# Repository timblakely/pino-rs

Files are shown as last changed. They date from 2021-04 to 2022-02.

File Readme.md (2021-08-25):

# Pino controller

Bare-metal BLDC controller for Pino the robot, written in
[Rust](https://www.rust-lang.org)!



-----

_**Disclaimer: I'm quite new at Rust, so please bear with me**_

This repository is currently a continuously changing, seething mess as I flail
around learning Rust. You're welcome to browse around the code, but please don't
expect proper, idiomatic Rust code just yet. For that I'd suggest the following
resources:

- [The Rust Book](https://doc.rust-lang.org/book/) - Seriously, read it "cover to cover" as it were. Coming from >15 years of C++ I debated whether it was worth reading the absolute basics, but I ended up going through it all and don't regret it one bit.
- [Embedded Rust Book](https://docs.rust-embedded.org/book/start/registers.html) - I know, I know, another book. But it's quite a bit shorter and more of a getting-started guide to getting Rust up and running in an embedded context.
- [m4vga-rs](https://github.com/cbiffle/m4vga-rs) - Not only is it a downright amazing implementation - 800x600@60FPS VGA on an STM32F4 (!) - the code is entirely in Rust and spectacularly well commented to boot! Definitely the place where I'm learning the most about Rust.

---

## Why rust?

I originally started the controller in C++, but found myself spending more and more time thinking about the language implementation, template metaprogramming, and wrestling with the inability to `constexpr` a raw address (can't `reinterpret_cast<Foo>` an address in a `constexpr`, but [don't take my word for it](https://www.youtube.com/watch?v=uwzuAGtAEFk&t=1217s)...), and less time on the actual controller itself. That's when I stumbled on Cliff Biffle's post with the contentious title "[Prefer Rust to C/++ for new code](http://cliffle.com/blog/prefer-rust/)". He posits that Rust was ready to replace C++ in most-if-not-all situations, _and that was back in 2019_. That post single-handedly convinced me to try out Rust, and I haven't looked back since.

## Building it

Don't bother trying right now; it doesn't really do anything :stuck_out_tongue_winking_eye:

But if you _really_ want to:

1. ```cargo build```
2. Connect your [NUCLEO-G474RE](https://www.st.com/en/evaluation-tools/nucleo-g474re.html), and follow the [Embedded Rust steps for adding the proper udev rules](https://docs.rust-embedded.org/book/intro/install/linux.html#udev-rules)
3. In VSCode, select `cortex-debug` launch configuraiton
4. Hit `F5`

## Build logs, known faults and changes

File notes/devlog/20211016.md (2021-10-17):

# Un-bricking STM32G4

Well that was scary. For some reason when Iw as flashing the chip it suddenly started saying "Error erasing flash with vFlashErase packet".
- Not sure what tripped it up, but no amount of disconnect/reconnecting or power cycling could revive the chip
- Thought I had fried it D:

Luckily I stumbled on [this thread](https://www.openstm32.org/forumthread2221) that had a solution:
- `openocd -f interface/stlink.cfg -f ~/git/rembed/tools/stm32g4x_custom.cfg` in one terminal to start OpenOCD session
- Then in another, run the following commands:

```
$ telnet localhost 4444
> reset halt
> flash probe 0
> flash protect 0 0 127 off
> exit
```

TL;DR: Somehow the flash protection got enabled, and the version of OpenOCD I'm using doesn't properly disable it before attempting to flash.

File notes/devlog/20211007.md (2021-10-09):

# We now return you to our regularly scheduled bot

Okay, I've been quite lax in self-documentation recently. Time to fix that!

I'm working on organizing my Rust workspace now. I've mainly been talking to the BLDC via Python->PySerial->FDCANUSB->BLDC, but something in that loop is causing some pretty serious latency, to the point where I can only poll at like 45Hz. That's waaaay too slow for any kind of monitoring. I suspect it's somewhere in Python+PySerial, so I'd like to cut that out of the loop. Then it hit me: if I like Rust so much, why not do the serial communication from Rust?
- First stab was the [serial](https://crates.io/crates/serial) crate. Buuuut turns out that hasn't been updated in 4+ years and is pretty out of date with modern Rust
- Next try is with [serialport](https://crates.io/crates/serialport). Better so far
- Also needed an `argparse` for Rust. [clap](https://crates.io/crates/clap) to the rescue!
  - The base configuration is a bit verbose/unwieldy, but it'll do for now.
  - [clap_derive](https://crates.io/crates/clap_derive) might help with that
-

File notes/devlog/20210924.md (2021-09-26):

# Closer to FoC

First up is moving away from the interrupt-driven angle calculation and instead towards a polling model. Done

Was trying to figure out why Ben was [casting the raw 0-1 encoder reading to an int prior to conversion to radians](https://github.com/bgkatz/motorcontrol/blob/2fa6cabbebcb19efb9d6b2dd0f59edc3537ad64f/Core/Src/position_sensor.c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)
  - I _think_ it has to do with the fact that you can set the mechanical zero (`M_ZERO` in his code) to any value within the range which can result in negative values, so it normalizes the corrected value from 0-1
- Interesting that he has an electric zero and mechanical zero separated

Now I guess all that's left is FOC...?
- I guess I do have to get the CORDIC calculations done, so I guess that comes first

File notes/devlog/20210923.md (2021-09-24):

# Encoder angle

Time to get electrical angle and velocity
- MA702 is already being auto-polled at 1kHz
  - Datasheet suggests new data is added to SPI every $1\mu s$
  - Doesn't really produce data changing that fast though since there's a ~390Hz filter cutoff frequency
- The stator has 12 poles, which gives us an electrical resolution of
  $\frac{2^{12}}{12}=\frac{4096}{12}=341.333$ ticks, or just over 8.41 bits

So how to deal with time...
- I've got three distinct time intervals:

1. The control loop of 40kHz (25us)
1. The MA702 polling loop via SPI of 1kHz (1ms)
1. The digital filter on the MA702 with a cutoff frequency of 380Hz (2.56ms)

- As far as I can tell I _think_ the last is accounted for with time delays in the control loop
- I can get the raw angle - both electrical and physical (EP) - easy enough; that's just reading the sensor
- The trick is how to calculate the _angular velocity_
  - It's required in two places: the finer grained direct EP angle via estimation, and the FOC calculations
- I think the underlying velocity calculation can probably be done within the `Encoder` struct, assuming we call an `.update(dt)` function once every control loop.

First up, get the MA702 to record velocity
- That'll require knowing the difference in time between updates. I guess only way to do that is by triggering on DMA
  - I guess I could use a timer, but would probably have to use a 32 bit timer; I'll cross that bridge when I have to
- Okay, have the DMA1 interrupt triggering
- Now I've got a bit of a problematic situation: both the DMA1 interrupt handler _and_ the 40kHz control loop need access to the result of the MA702
  - DMA1 needs it to read the encoder value and calculate the angular velocity and acceleration at 1khz
  - The control loop needs it to update the Encoder's finer grained representation via $\dot{\theta}=\ddot{\theta}dt$ and $\theta=\dot{\theta}dt$
  - I _think_ I may have conquered this problem once before via `BufferedState`. The high frequency control loop is read-only, so the lower priority DMA1_CH2

Okay, got that going. Seeing some odd readings on the raw_angle though... it's supposedly 12 bits but it's going to ~4658
- Thought it might have been garbage being written, but turns out I had `>> 3` instead of `>> 4`

Oof, running into a gotcha with buffered_state: I can't count on previous values being correct since the state is being double-buffered; the previous value would be in the other state
- Looks like I'm going to have to add one more layer of indirection to avoid blocking the control loop
- Wait, actually this works out pretty well: I can use the other buffer as the previous value since it's read-only in the `StateReader`
- Yup, that works. Now able to get the angle at 1kHz and soon interpolate it even more
- Though now that I look into it, it seems like in spite of the filter being at 380Hz, it can produce data faster than that, at up to 1MHz... so this might have been superfluous?

Working on DMA auto-transfer from MA702, but something's a bit weird...

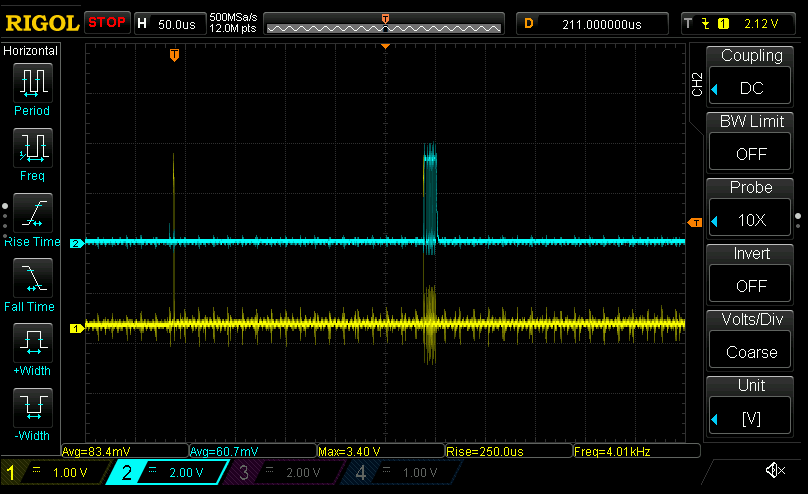
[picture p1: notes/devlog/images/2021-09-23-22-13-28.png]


- That first yellow pulse is when I enable the interrupt. That second yellow pulse is when the DMA transaction complete signal hits. That transfer _should_ be driven by the SPI completion
- But instead it appears to be on when the SPI transaction _starts_
  - Digging into the DMA settings now; I likely swapped `DMA[CH1]` (used to trigger the SPI transaction) and `DMA[CH2]` which is triggered by the SPI frame completion
- Aha! That's more like it

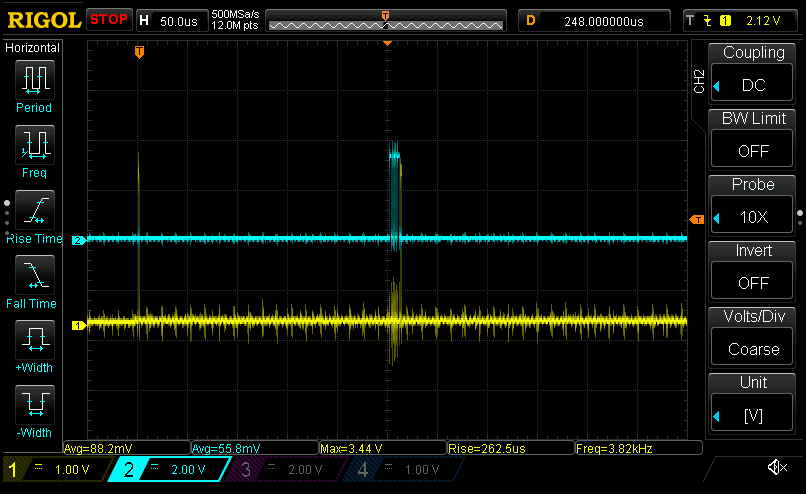
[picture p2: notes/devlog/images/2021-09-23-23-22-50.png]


  - Zooming in:

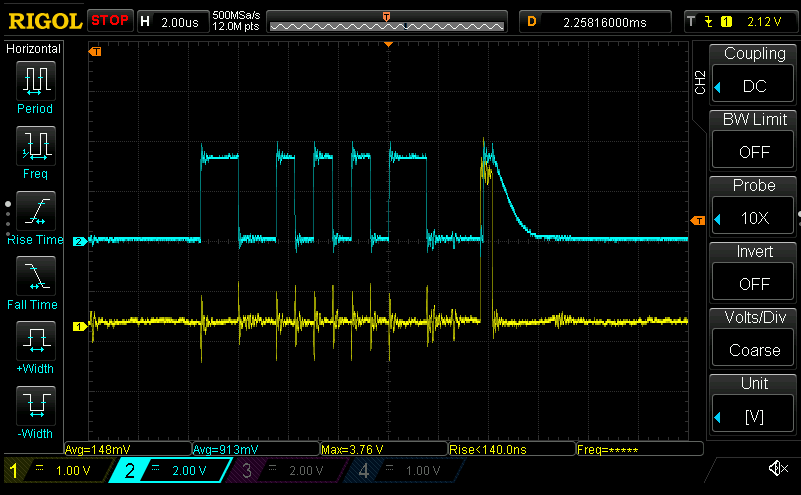
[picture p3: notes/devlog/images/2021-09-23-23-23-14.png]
    

  - Copy-and-paste strikes again... I had set up `DMA[CH1]` trigger correctly, but during copy/paste setting up `CH2` I didn't end up changing the DMA trigger from `TIM3_UP` to `SPI1_RX`
  - Oops? Oh well, at least it was pretty quick to fix
- Ooh, wait... since this is done via DMA I wonder if I can poll the encoder _even faster_ than my control loop
  - The DMA controller can execute a write every 4 AHB cycles, which mens at 170MHz it can run at 42.5MHz
    - Pretty overkill, since the SPI is only at like 5MHz or something like that :sweat_smile:
  - Looks like as long as I don't use the interrupt-driven version I can poll it at 100kHz and have about 4us of play assuming I run the SPI at $\frac{170MHz}{64}=2.656MHz$

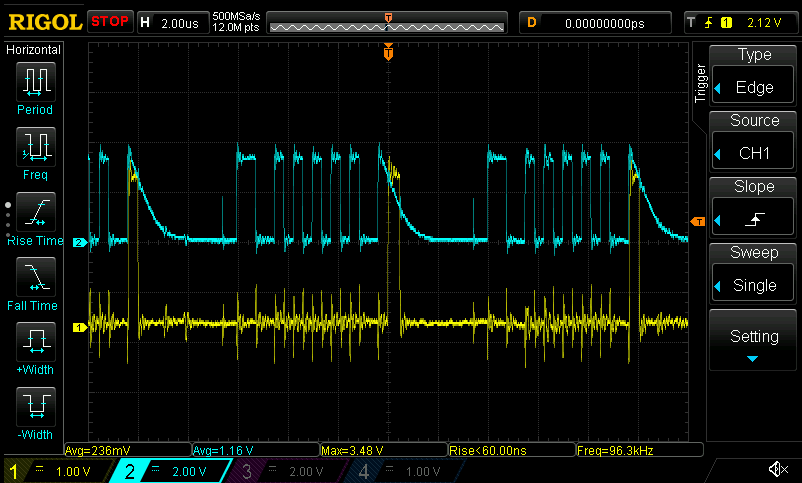
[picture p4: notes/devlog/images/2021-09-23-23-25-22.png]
    

- 100kHz is complete overkill of course since I'm only actually reading the value once every 40kHz in the control loop
  - But there's one big advantage to doing it via DMA: there's effectively zero overhead during the control loop waiting for the SPI to read out the angle
  - Even assuming you're doing it asynchronously, unless you pack various other instructions _perfectly_ between the start-SPI-read and read-out-once-SPI-transaction-is-done you're going to be wasting upwards of 1-5us
  - That doesn't sound like much, but when your control loop is operating at 40kHz that means you've got 25us _total_ to play with

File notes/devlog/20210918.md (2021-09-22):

# Controlling the currents

We have current control! :zap:
- Took me a while to realize what the issue was that was causing runaway current after about 20 timesteps
- But realized by PWMing phase A to get a current on phase A, the current measured is actually negative
Makes it hard to reach a positive current... :sweat_smile:
- Now to implement rudimentary FOC and we should have some motion!

So it's _really_ noisy due to ~~my boneheaded mistake~~ issues with the ground plane, but it looks like I have current control for sure
- Here's me commanding -1.5A on Phase A, as measured from the output of the DRV8323's CSA

  

- And here's the response asking for -3.5A

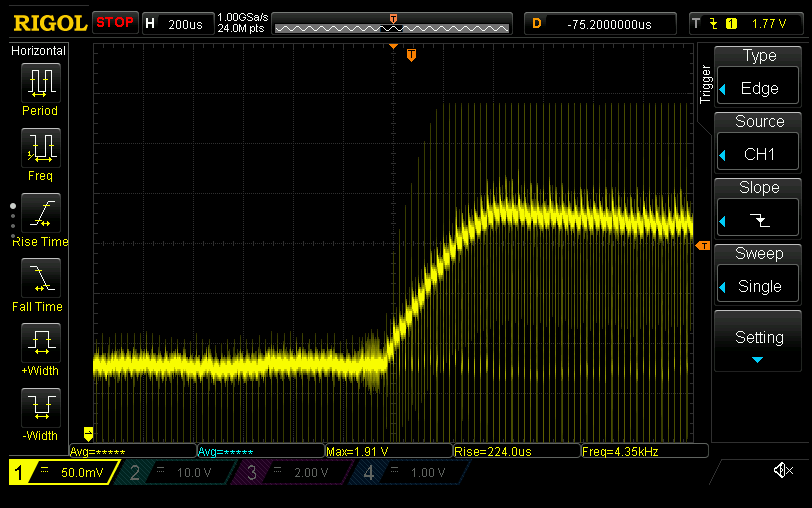
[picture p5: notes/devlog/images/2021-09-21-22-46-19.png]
  

  - Ugh, that noise is going to drive me absolutely _nuts_ until the global semiconductor shortage is over and I can actually fab new boards
    - Which will be approximately.... never? :sob:

- If you squint really hard though, there's actually a control loop there that looks just about what I'd expect given my modeling
- On top of that I don't really have a good place to ground my probe, so I'm literally steady-pinky-holding the ground clip to the negative side of my bulk caps, which I'm sure is great for noise suppression...

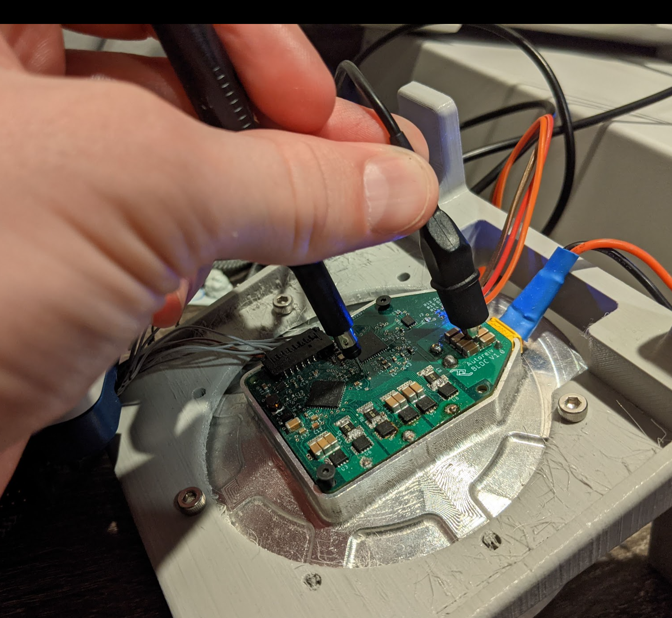
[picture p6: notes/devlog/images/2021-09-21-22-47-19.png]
 

  - Why yes, now that you mention it I _am_ going to be 1) adding a ground pad to clip onto on rev 1.1 and 2) getting a proper PCB probing setup when I finally move to a workshop bigger than a shoebox
    - Please don't judge me too harshly on my SMD soldering skills... this was my first board design, SMD soldering attempt, use of 0402 parts, flux, and a heat gun ever (honestly I'm gobsmacked it turned on at all)
  - You better believe I'm going to be upgrading the I-can't-believe-it-hasn't-broken-yet debug header/wiring for rev 1.1 :zany_face:

So here's something interesting... I was wondering why I was seeing some nice, smooth current control curves like this commanding -6.5A on phase A

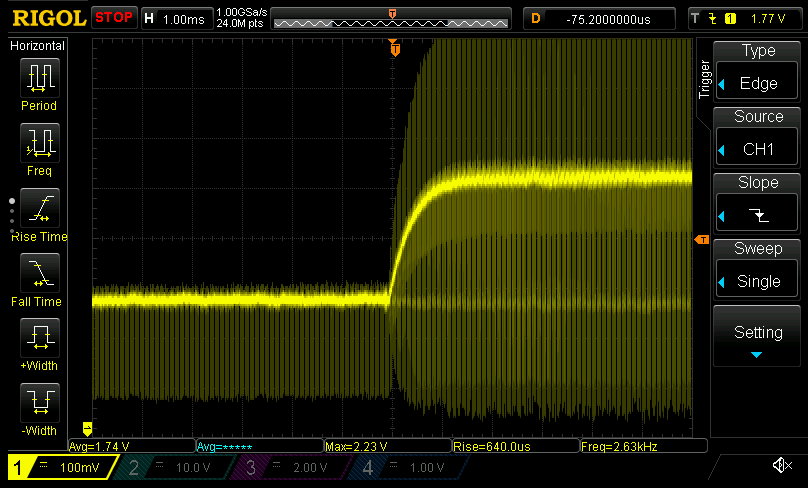
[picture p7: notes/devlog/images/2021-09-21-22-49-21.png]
  

- That definitely looks like a controlled rise; all good!
- But the rise time to peak was 1ms. That's borderline "wait, [wat](https://www.destroyallsoftware.com/talks/wat), that's pretty slow, and way too slow during any kind of gait to be changing torque targets"
- This is in contrast to Ben's controller could hit the appropriate currents in <= 500us

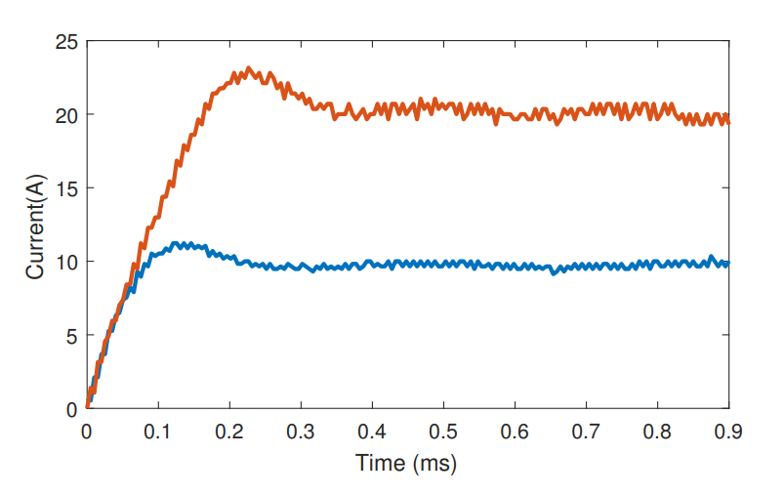
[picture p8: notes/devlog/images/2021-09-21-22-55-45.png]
  

# ***SIGH***

I had Forgotten yet ***another*** hardcoded value I added to the codebase
- Back when I was doing inductance and resistance measurements/calibration, I couldn't allow the PWM to get higher than a certain value or risk driving 100A through my stator
  - Just trying to prevent this (not mine, thankfully!)

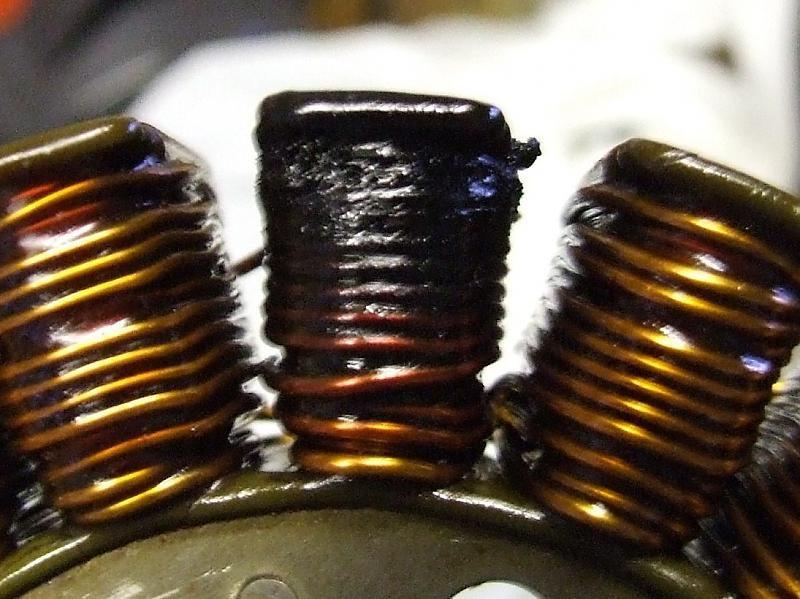
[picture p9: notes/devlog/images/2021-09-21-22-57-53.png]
    
- With that hardcoded value my current loop was clamped to driving a maximum of +/- 1.5V in case the current loop didn't work
- Remove that and lo and behold: I can hit 0->10A in just over a hundred us, just like Ben's case above

  

  - Note that his simulations above are running faster than the 40kHz my measurements are made at. From what I can tell from the graph above the motor sim is running at a loop speed of 100kHz

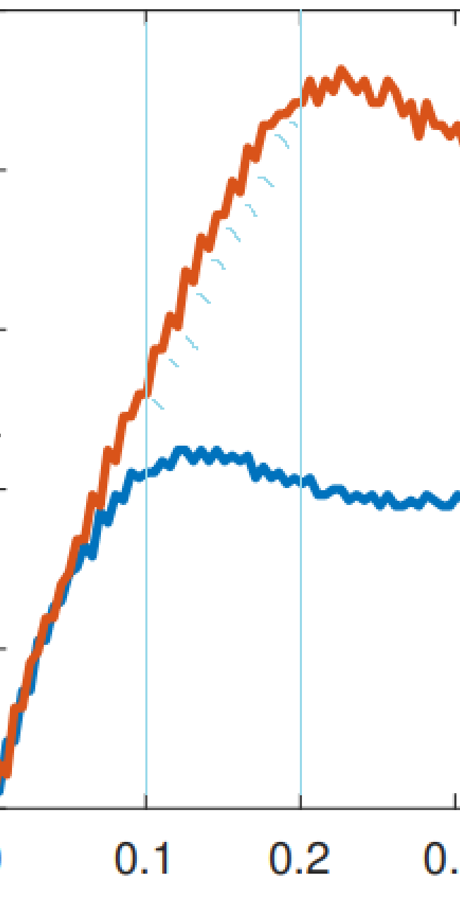
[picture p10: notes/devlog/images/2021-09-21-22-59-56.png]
    
    - (That's 10 ticks per 100us)
  - He had a (much) older control loop running at around 10kHz that reached a step function of 1A in about 1.55ms, so this seems acceptable

    
- Again, my k/ki are probably way needlessly accurate, but hey, can't complain with a bit more performance

Last amusing anecdote for the evening
- Was wondering why I couldn't get above 16A on my current step
- ... turns out I had yet _another_ (***are we seeing a pattern yet Timmay?!***) hardcoded limit that said if the board detected a current above 20A to shut down
- So considering my amplifiers are a bit noisy and there's probably a bit of overshoot for the control loop, I added a low-pass filter on the phase current (`alpha = 0.01`)
- ***BBZZZZTTTT*** aaaand my psu started going nuts
  - ... oh, I had the current limit set to 1A and OCP set to 2.5A. No wonder it couldn't supply 16A :zany_face:

    

Alright; TL;DR for today:
- I have current control, and didn't blow up my stator getting to this point :sweat_smile:
- In addition to that: my inductance calibration + resistance calibration + control loop gain calculations were accurate enough to effectively auto-tune a control loop for 2kHz bandwidth! :tada:
- Just a few more steps away from FOC commutation

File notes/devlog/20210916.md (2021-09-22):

# Bad inductor, bad

Hm. Well, looks like I'll have to dig back into the inductance calibration code again :/
- On one hand, hooray my LCR meter came today!
  - AFAICT it's a not-entirely-terrible cheapo LCR meter that trades a crappy updates-once-per-second display for somewhat accurate internals
  - It's not a great one by any means, but I've tested it against a few Cs and Ls that have a known-ish value and it's surprisingly accurate
  - [DE-5000](https://www.amazon.com/gp/product/B00S298KJO/) - Amusingly even the instructions were in Chinese
  - It's a step up from the typical craptastic LCR meters since it does variable frequency measurements at  100, 120, 1k, 10k, and 100kHz
  - Still definitely better than the ~$35-range ones
  - One positive: it can measure DC resistance down to 1/100th of an ohm, which is nice (two (three?) orders of magnitude better than my decent multimeter)
- On the other hand it's measuring an inductance of ~100uH whereas my calibration routine above said it was around 25uH :thinking:
- Being close is fine, but being off by a factor of 4x is Not A Good Thing™️
  - Dang... was hoping to have solved the inductance issue

The inductance measurement from the LCR of 100uH was phase-phase, not overall
- I suspect it's due to a bug or two in my inductance measurement code. At this point - considering I've already found one bug - I trust the LCR more than my calibration code
- Given the square wave I was driving through the stator was going through A and out B and C, that means I've got a few in series
  - Which means each individual phase is < 25uH I was measuring...
- Yeah, something isn't quite right :/

I was initially thinking I wasn't doing the ADC conversion correctly
- But the v_bus rail I'm reading through ADC4 shows... wait for it... gotta remember how to do it :sweat_smile: ....
- 23.91V. That does seem a bit low, given the PSU rail output is almost exactly 24V
- But I don't think a 0.375% error can make a 4x difference in inductance measurement...?
- Just really wish I hadn't screwed up the ground plane... really going to limit my current loop bandwidth with how noisy phase B is :/

  

***sigh*** And yet again, turns out very likely [PEBKAC](https://en.wikipedia.org/wiki/User_error)
- `let v_ref = v_bus * 0.03; #PWM hardcoded to 0.03` ***Not if it's a parameter you're sending now that you've changed the loop to be configurable via FDCAN!!!*** :woozy_face:
- TL;DR: Timmay is a dummy... turns out when I correct that hardcoded value above to the correct PWM'd value I get anywhere from 100-112, which is exactly what the LCR meter suggests it should be
- 
- Silver linings? 1) My inductance calibration now works (ish) 2) I have zero buyers remorse from the LCR meter :zany_face:

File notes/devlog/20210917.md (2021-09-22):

# Current control loop design

Okay! I think, after ~~a few days~~ ~~weeks~~ _entirely) too long, I think I've gotten all the
parameters set up to do my PI controller loop!
- Can now calculate the $k$ and $k_i$ values I need, and the loop gain to translate from current to voltage
- Here's a bode plot (please do ignore Octave's terrible UI) of the control parameters I've measured

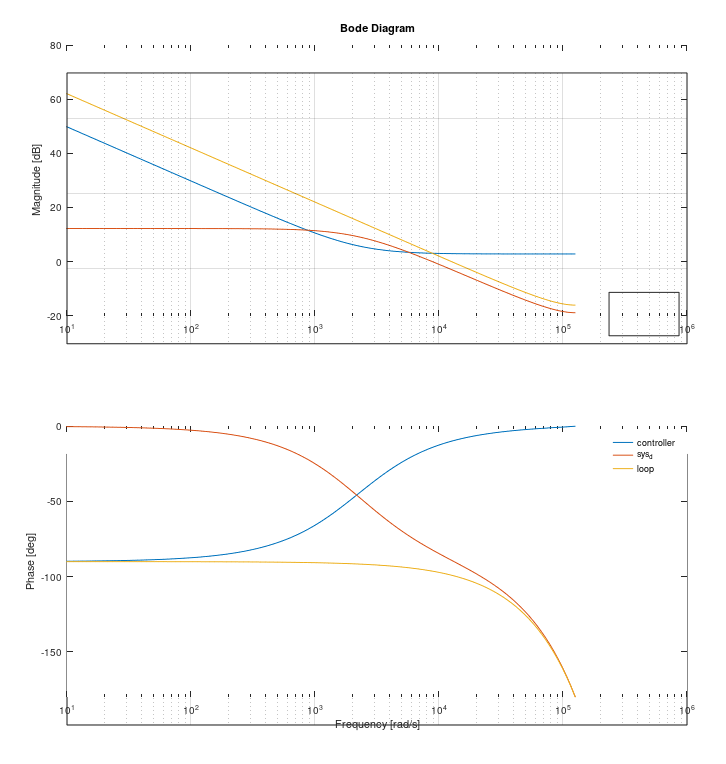
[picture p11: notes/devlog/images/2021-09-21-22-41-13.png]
  
- That's with a loop bandwidth of 2kHz (and a PWM/sensing loop of 40kHz)
- Given my awful ground plane goof, I'll probably lower that to something like 1.5-1kHz
  - Makes up for the fact that there's a tiny vuvuzela blasting its little heart out at 700kHz on Phase B :trumpet: :woozy_face:
- Decent phase and gain margins too

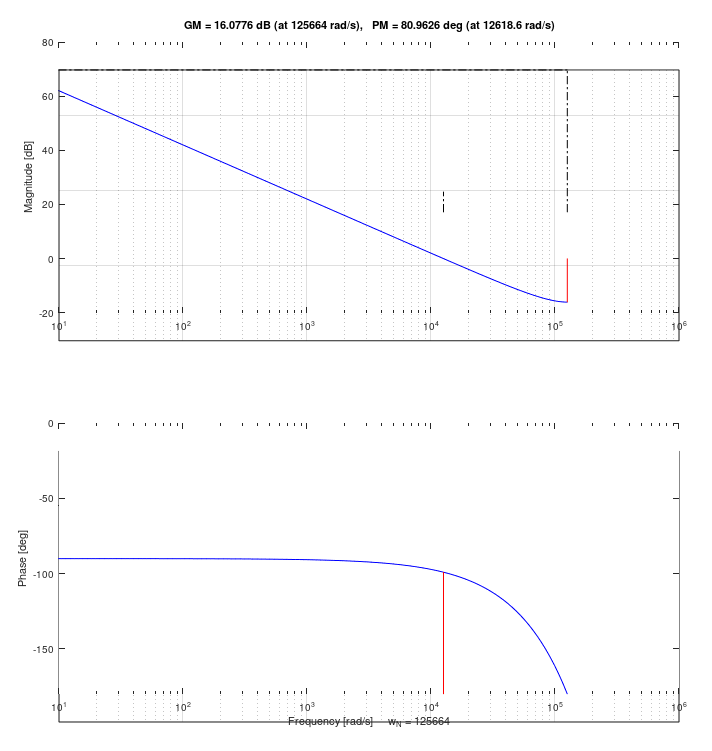
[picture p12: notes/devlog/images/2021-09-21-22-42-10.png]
  

I realize I'm just going through the motions here with regards to control theory
- Any quad motion/feedback that's likely to happen in a physical system is almost certainly going to be an order of magnitude lower than the loop bandwidths I'm targeting
  - It's mainly about some blend of "trying to understand what's going on" and "trying not to asplode anything since I barely know what I'm doing", in just about equal parts :sweat_smile:
- Step response going from 0-1A on the theoretical controller

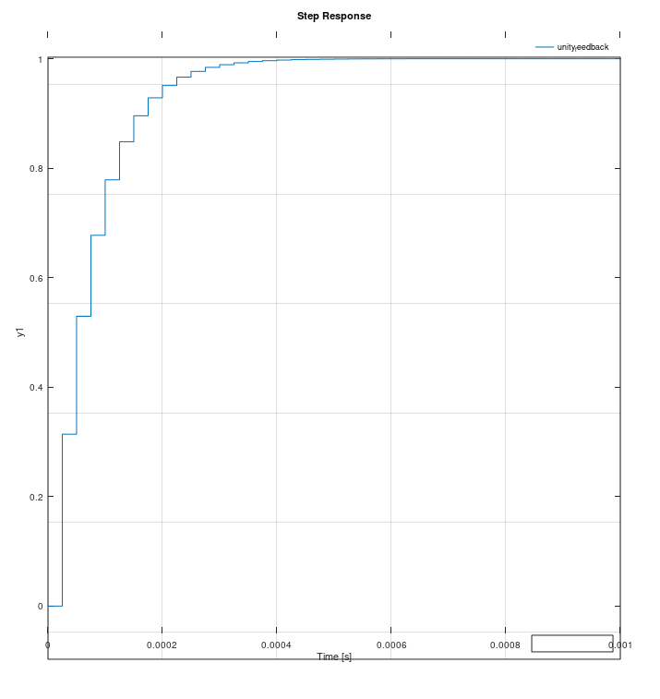
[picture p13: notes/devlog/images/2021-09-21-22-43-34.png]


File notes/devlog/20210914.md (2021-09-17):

# Current loops

Working on figuring out the current gains on the following assumptions:

- Inductance: 24-26 $\mu H$
- Resistance: 240mOhm

Going to work through Ben's model, Appendix C from this thesis.
- Electronic dynamics of the system (RL) are several orders of magnitude faster than mechanical, so reasonable to ignore those dynamics

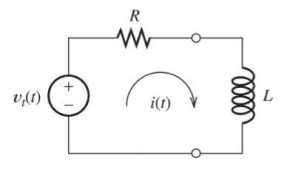
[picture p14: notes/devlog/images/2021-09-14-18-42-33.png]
  
- Continuous time _system_ transfer function is $\frac{\bar{Y}(s)}{\bar{u}(s)}=\frac{I(s)}{V(s)}$
  - $V(t)=\underbrace{L\frac{dI}{dt}}_{inductor} + \underbrace{RI(t)}_{resistor}$
  - Laplacian gives us $V(s)=LsI(s)+RI(s)$
  - Building transfer function:

$$
\frac{\bar{Y}(s)}{\bar{u}(s)}=\frac{I(s)}{V(s)}=

\frac{I(s)}{LsI(s)+RI(s)}=\frac{I(s)}{(Ls+R)I(s)}=\frac{1}{Ls+R}
$$

- - Neat, derived that on my own and it matches Ben's results :)

So system transfer function is $\frac{1}{Ls+R}$
- Looks like there's a pole at $s=-\frac{R}{L}$
- Note that in the standard format the $\frac{1}{as+b}$ means it has a DC gain of $\frac{1}{b}$, or in this case $\frac{1}{R}$ ([good resource](https://www.allaboutcircuits.com/technical-articles/understanding-transfer-functions-for-low-pass-filters/))
  - DC gain is the $abs$ gain in Ben's bode plots

    
- Keep in mind that this is the _system/plant_ transfer function, not the true _loop_ transfer function that includes the controller $K$

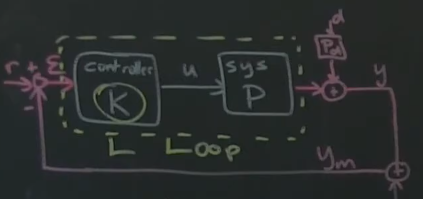
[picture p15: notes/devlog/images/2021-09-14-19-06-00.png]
  
  - That means the whole loop transfer function of the whole system is $L=PK$

Note that $\frac{1}{Ls+R}$ is in _continuous_ time, and that's not where we operate; we're in discrete
- Conversion from continuous to discrete via [z transform](https://www.youtube.com/watch?v=14cMhrp5wlk&list=PLUMWjy5jgHK0MLv6Ksf-NHi7Ur8NRNU4Z) ([neat visual representation](https://www.youtube.com/watch?v=acQecd6dmxw))
  - $\mathcal{Z\left(f[k]\right)=\sum\limits_{k=0}^\infty}f[k]z^{-k}$

  
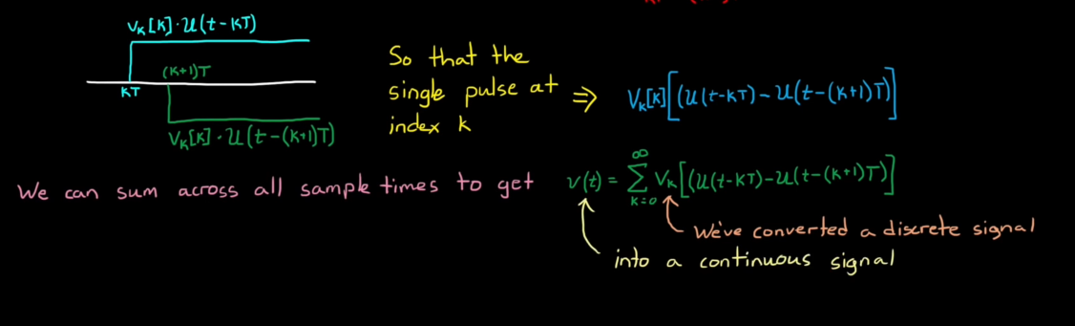
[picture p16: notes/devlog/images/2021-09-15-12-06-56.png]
  
  
  
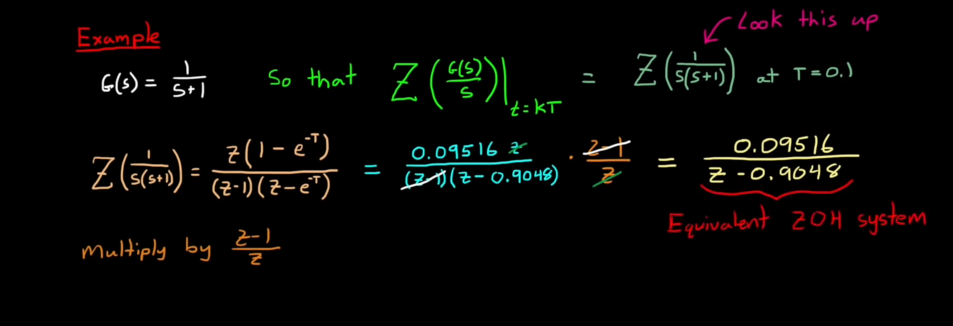
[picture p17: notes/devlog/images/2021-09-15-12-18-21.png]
  

Ben used a zero-order-hold conversion to discrete time

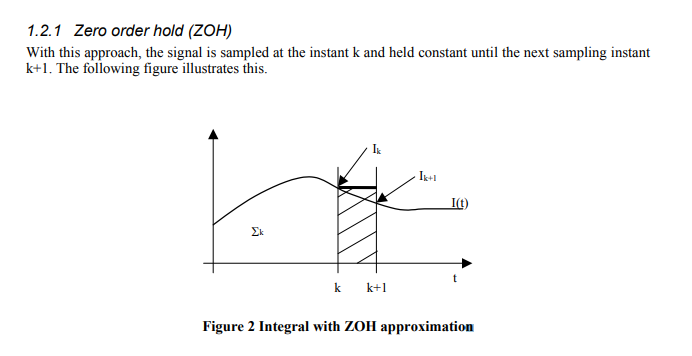
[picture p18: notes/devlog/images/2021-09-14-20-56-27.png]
  

  ([source](https://www.analog.com/media/en/technical-documentation/application-notes/PI_ctrl.pdf))

  $U(z)=K_p\cdot\left(1+\omega_{pi}\cdot\frac{}{}\right)$

  $\liminf\frac{1}{x}$

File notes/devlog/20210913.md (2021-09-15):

# Easy goal: measure resistance

Hopefully a quick goal this evening: measure the phase resistance for phases A/B/C

Less quick than I'd have hoped since I was getting some slightly odd values of 330+ mOhm, but got it
sorted
- _On tonight's riveting episode of "Graphs Nobody Should Care About" we bring you... phase resistance!_

  

  - Looks like I'm measuring around ~240 mOhm asymptotically
  - The end dip is my ControlLoop hardcoded limit of 0.08 duty cycle kicking in
  - Note that this is sensing for only 0.25s. I can probably get a slightly more accurate reading if I sensed for longer
- The motor manufacturer claims they can sustain 8A continuous, but a) that almost certainly has to be over-estimated by a decent margin and b) given the global silicon + supply chain armageddon I reeeeeeeeeeeeeeeally don't want to destroy one of my <= 3 actuators I have for the next 1-5 years D:
- You know what, here goes nothing. Going to try to measure for - ***gasp*** - 0.5s. Will report back either with results or very-angry-at-himself-for-knowing-his-luck-gonna-wreck-his-stator-Timmay...
  - Reporting in: neither my stator nor house are on fire :fire:
  - Again, very similar response:

    
  - Asymptotically it's right around 240 mOhm yet again
  - 240 mOhm is right in line with what I can measure with my multimeter across a single phase: 0.1<R<0.2 Ohm

Okay Tim, STAHP characterizing the motor already!
- We have inductance and resistance of the motor now
- We can pass it on to Future Tim to design the current control loop gains

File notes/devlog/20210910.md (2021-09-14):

# The Case of the ~~Missing~~ Noise

This ADC noise is really starting to bug me
- First up I moved calibration to be done via a `ControlLoop`, currently triggered via RPC
  - Probably can set this during startup, but for debugging purposes this is fine
- Before/after calibration:

  
  - Pretty cool that I can do this via Python now
  - Looks pretty good, but then there's still some wonky noise on ADC2:

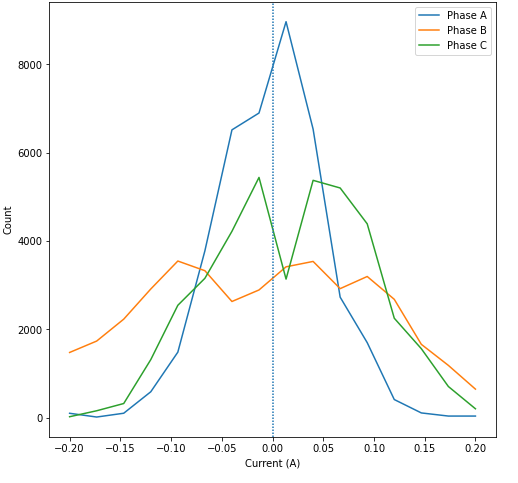
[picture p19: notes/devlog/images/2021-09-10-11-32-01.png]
    
- Okay, I just convinced myself it's switching noise. Here's a trace of Phase B's sense line:

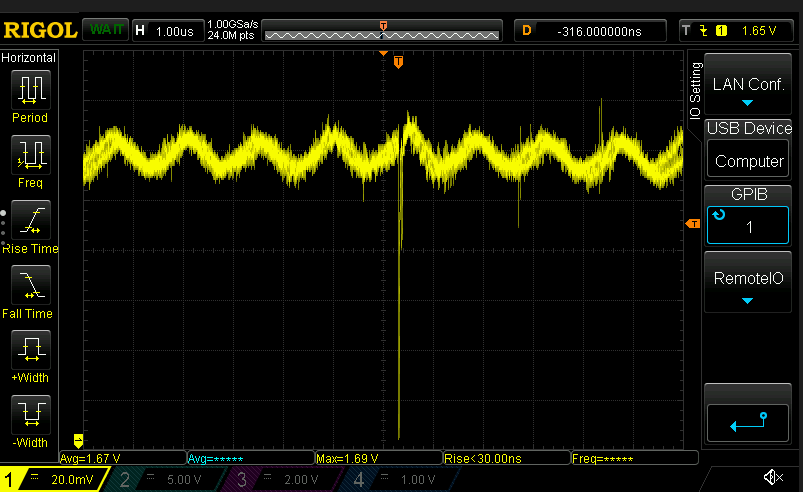
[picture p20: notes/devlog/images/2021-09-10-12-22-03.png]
  

  - And guess what? If you zoom out a bit and do an FFT...

  

  - Ayuuuup. 700kHz. And guess what the switching frequency of the DRV8323R is... :woozy_face:

- Here's a probe between the 24V ground and the logic ground:

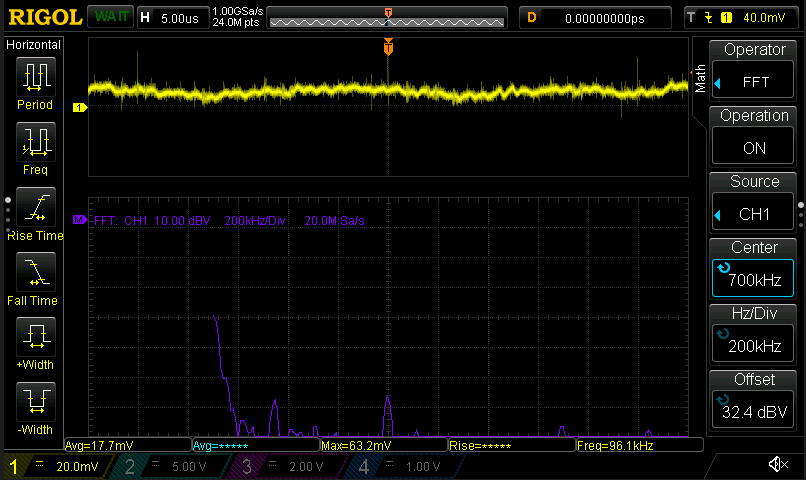
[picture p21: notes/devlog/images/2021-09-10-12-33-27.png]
  

  - No getting rid of it on this board revision :(

Turns out I made a ***major*** screw-up when designing this board revision: I split the ground plane

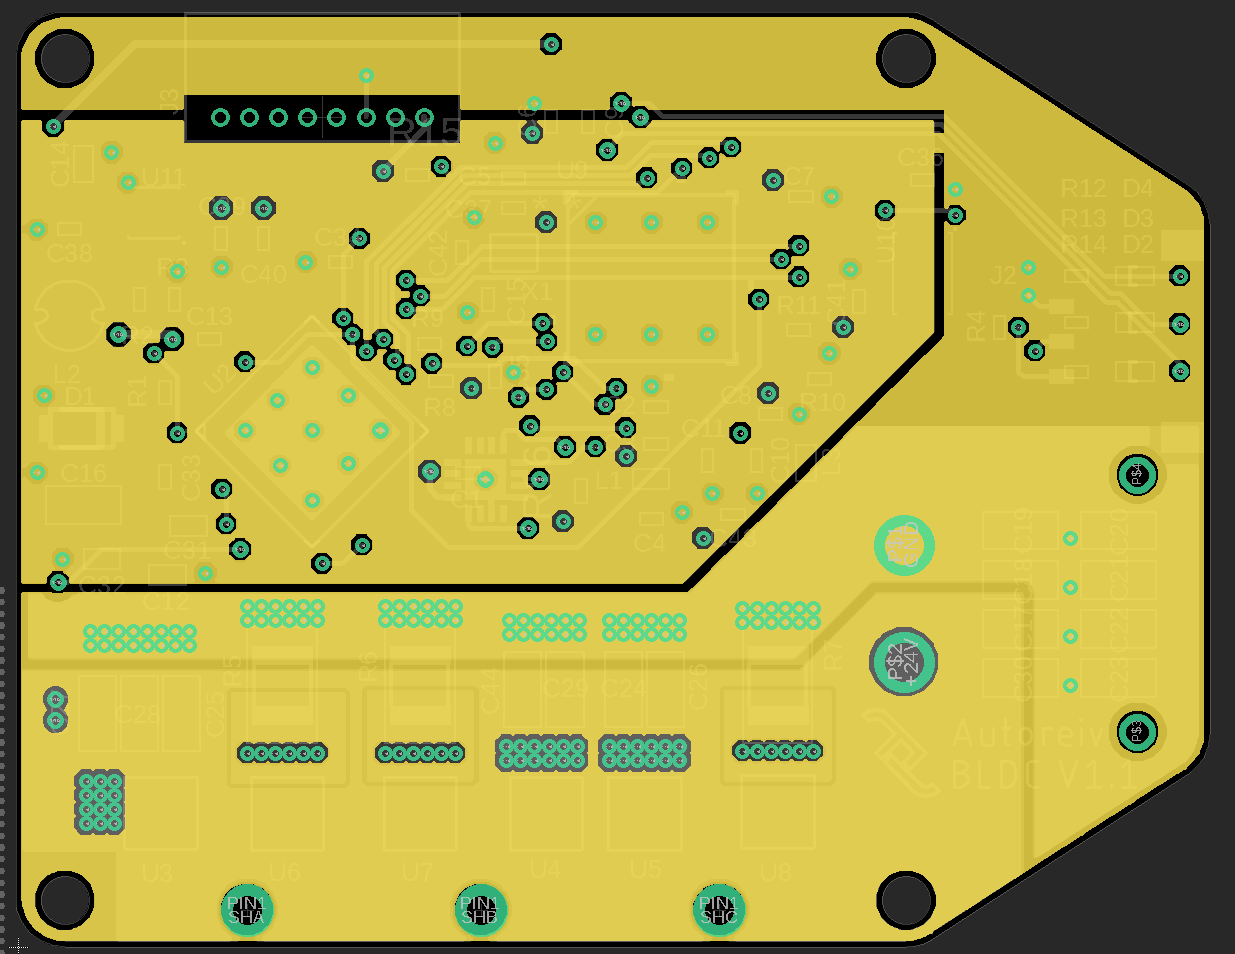
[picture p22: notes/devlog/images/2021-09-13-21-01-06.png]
  
- It's apparently [one of the worst things you can do](https://learnemc.com/some-of-the-worst-emc-design-guidelines)
- Pointed out by @SkoomaDentist in [Amulius](https://discord.me/amuliusengineeringchill)
- Nothing I can do about it now. Hopefully the controller will be able to deal with it :/
- Next revision:

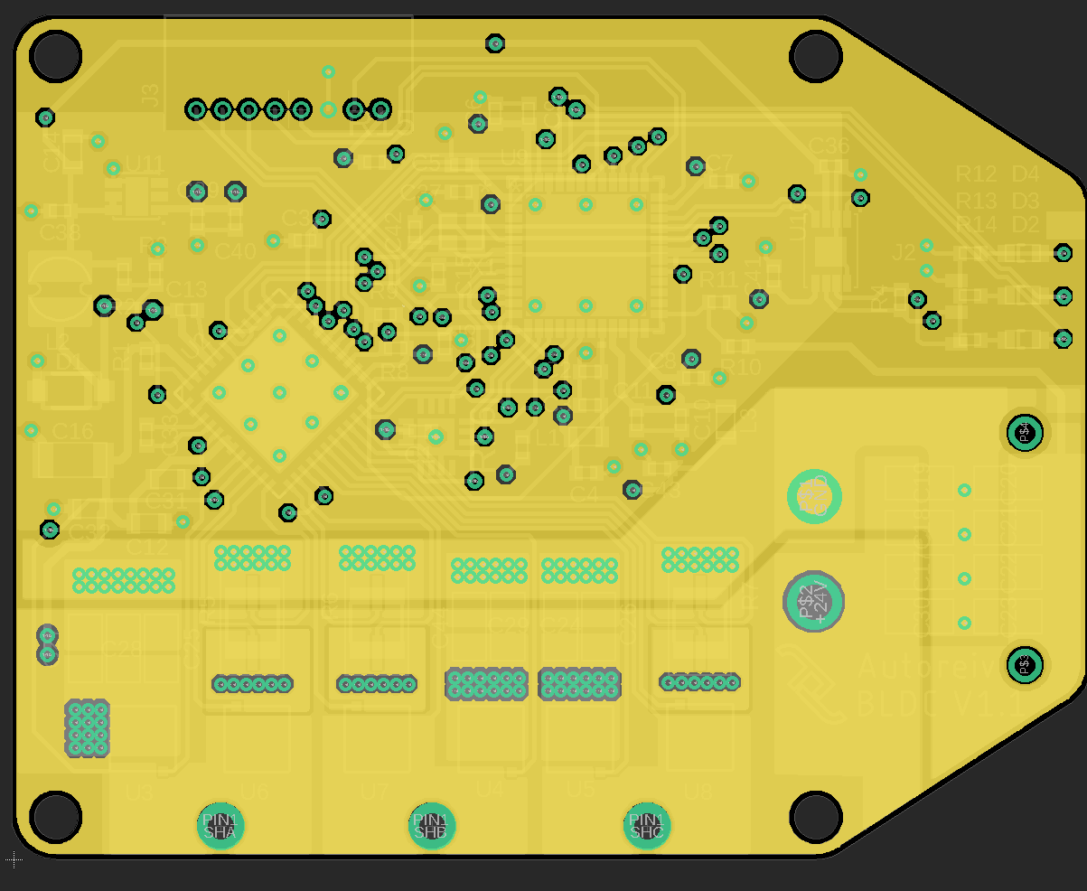
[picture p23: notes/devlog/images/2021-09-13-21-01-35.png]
  

Okay, next up: reorganize the commutation folder a bit. Done.

Now to the inductance measurement
- Since there is no current control in this loop, the PWM duty cycle is hard-coded to be no more than 0.03, which at 24V and a winding resistance of 0.2R yields 3.6A. The windings I'm using are rated for 8A continuous and would very likely be able to handle much more, but I don't want to fry anything right now :)
- I first need to make sure the ADC is calibrated properly, which is its own `ControlLoop`
  - Kind of in an awkward spot as to when `ControlLoop.finish()` is called
    - Right now it's called from the interrupt _immediately_ after the control loop is finished
    - Works okay for now, but it does mean I can't chain commutators easily :/
  - Stopgap is to enforce that calibration happens on the driver prior to it entering the run state.

So I think I might have something sane? I'm reading 160μH which seems somewhat in the ballpark. Let's check the current traces
- First I should set it up to be triggered from python so I don't have to keep re-flashing.
- That works, but now release mode is getting stuck on `adc5` coming out of enable state?
  - It's sleepy, apparently. Needs a few microseconds to get out of calibration mode?
- Looks like the measurement is close to working, but it's not respecting the flipping; seems to be flipping every commutation
  - Yup, forgot to clear loop variable

Hooray, I've got a singing actuator! :musical_note:
- Here goes nothing... going to sweep through a few durations and frequencies. Hope this doesn't burn up the stator
- And we have inductances!

  

  - This was done flipping Phase A high and B/C low, and vice-versa, switching the polarity of the square wave voltage at Freq
  - Doesn't look terribly stable, but on A (the one I'm actually calculating it on since B and C don't necessarily have the same resistances) it's a standard deviation of 1uH at the longest calibration time which is more than good enough to calculate current loop gains :thumbsup:
  - And an inductance of 100uH seems to be in the ballpark of where I'd expect it to be

_TODO(blakely): Initialize timer in control loop_

Okay, now trying to characterize the inductance
- The [falstad sim](https://www.falstad.com/circuit/circuitjs.html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) suggests that a higher frequency implies less losses
- I saw that in _one_ graph of all the characterizations I did, but now I can't

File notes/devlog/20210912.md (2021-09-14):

## It's the final ~~countdown~~ inductance measurement!

Okay, I'm really going to make an effort to get the inductance measurement down now. Doing a few
more parameter sweeps to really characterize it
- I'm doing voltage control via PWMing, so an additional parameter is Duty Cycle (aka Voltage)
- The inductance measurements are going to be more accurate the more voltage I put into the square wave
  - That said, I can't put a full +/- 24V across it since the coils only have a resistance of 0.2R which would be tossing upwards of... 120A through the coil. Yikes!
- So I'll need to make sure I keep the duty cycle down to something reasonable
  - The motor's rated for 8A continuous, so I figure 5s at 8A peak is fine
  - That 8A translates to about a 15% duty cycle when doing a 4kHz square wave, assuming my [Falstad sim](https://discord.com/channels/772467083370823710/772543427640295455/886714568422862858) isn't too far off
  - Higher frequency square waves should be much lower than that peak
- 15% duty cycle at 4kHz square wave

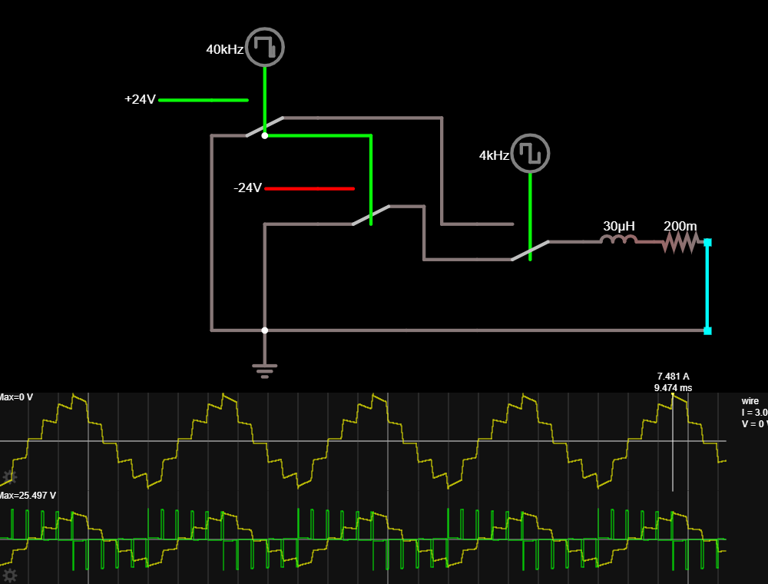
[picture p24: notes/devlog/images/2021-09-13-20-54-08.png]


- Can't go too much slower square wave than that due to a few reasons:
  1. The peak current would be around 18A
  1. The the true triangle output wave approximation breaks down
  1. The resistive losses during pwm-down periods get pretty lossy

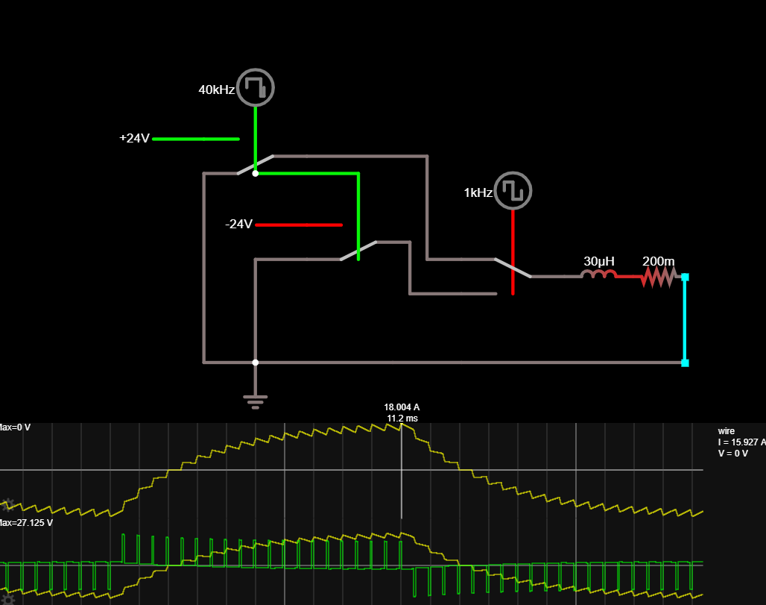
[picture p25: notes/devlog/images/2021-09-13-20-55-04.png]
  

  - The last doesn't change too much for different frequencies, but at least for higher frequencies the approximation is a bit better
- Let's see where that gets us...
  - [Let me sing you the song of my ~~people~~ stator](https://photos.app.goo.gl/AEF8fjNLeESPyhRq8)
  - And bingo! The duty cycle's affect on inductance measurement:

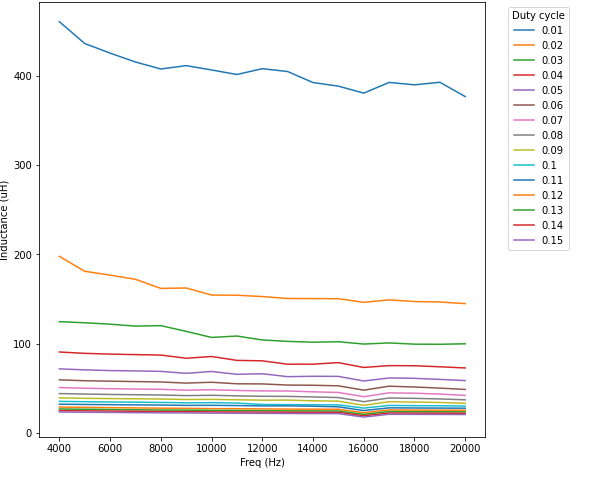
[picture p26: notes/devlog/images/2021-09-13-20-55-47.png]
    

  - Aside from an interaction at 16kHz (I suspect that magic frequency does not keep the triangle wave zero-centered), it's a pretty good successive estimation:

    

  - All duty cycles show asymptotic behavior:

    
- Aaaaand... we have an inductance! Exponential curve fits for all these line up with a final approximation of 16-17uH

  

  - ... wait, that seems a bit low
- Solution: stop being a cheap-ass and buy an LCR meter :sweat_smile: (but if nothing else this is a good exercise! :upside_down:)
    - The silly part is I'm spending way too much time on this. I'm literally using the same stators as Ben did, so I could just use his 30uH measurement...
    - But... _whyyyyyyyyy_ did he use that value?! :rofl:
- Aha, here's something... I think I was sampling too late in the ADC cycle; I originally was sampling in the PWM deadtime like you're supposed to do for FoC, but that's much later compared to the PWM square wave
  - So it turns out sampling period doesn't matter nearly as much as I thought it would...? I guess that's good?

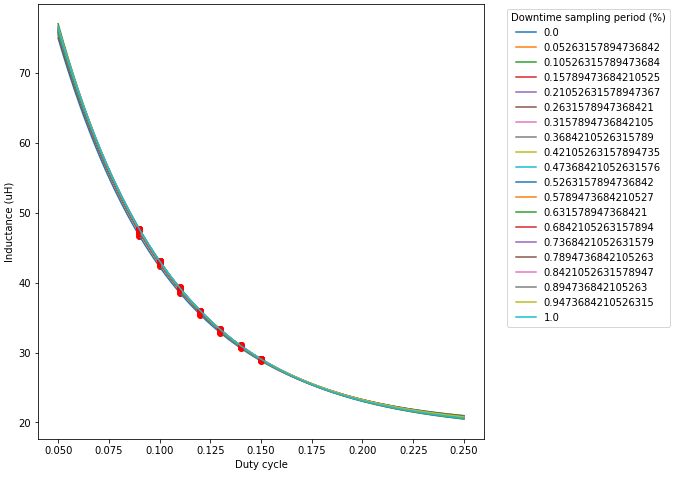
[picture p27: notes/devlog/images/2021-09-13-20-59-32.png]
    

  - That's varying the position of the sampling trigger, where 0.0=sampling immediately on the falling pwm edge, and 1.0 is measuring in the dead center of the PWM downtime
  - On the one hand that's nice to know that there isn't too much noise on the ADCs that the exact time of sampling doesn't matter too much
  - On the other hand, I'm getting asymptotic inductances of like ~20uH, which is much less than Ben had (he measured 30uH)
    - (Caved and bought an LCR meter; supposedly arrives Friday, so I should have some ground truth soon-ish :sweat_smile: )

Okay. So gonna call it "okay" for now
- I've figured out the variables that affect the inductance measurements, and with an "optimal" 2s testing time I'm seeing a whole bunch of reasonable measurements that suggest this motor is right around 24-26uH, which is about an order of magnitude better than I realistically need the measurement to be :zany_face:



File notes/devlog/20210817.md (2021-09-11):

# The search for Inductance

Okay, after flailing around watching entirely too many hours of YouTube on [control systems and bode
plots](https://www.youtube.com/watch?v=O2Cw_4zd-aU&list=PLUMWjy5jgHK1NC52DXXrriwihVrYZKqjk&index=12),
it looks like I'm going to need to accurately measure the motor's inductance.

I initially tried to do this with a simple RL time constant using a battery and another winding, but
that was unsatisfactory. Going to attempt to do what ODrive does and drive a zero-centered square
wave through the phases, which should [result in a triangle wave of current through the
inductor](https://www.falstad.com/circuit/circuitjs.html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). Measuring current over time should give us the inductance via $V=L\frac{di}{dt}$. This appoximation holds as long as the square wave duration is $\llless$ inductor time constant $\tau$.

But this gets a little dicey though, since we don't want to drive +/- 24V through the windings;
that'd burn up the stator in no time flat. So we're going to have to PWM it, which results in some
[really gnarly
waveforms](https://www.falstad.com/circuit/circuitjs.html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):

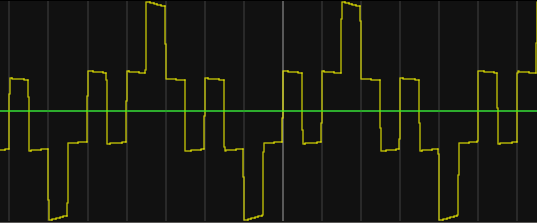
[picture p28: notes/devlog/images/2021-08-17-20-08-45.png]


That's apparently ... okay? Some back of the envelope calculations from
[Falstad](https://www.falstad.com/circuit/circuitjs.html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)
suggest something like a 40kHz PWM taking voltage down to ~2V (8.33% duty cycle) and a square wave
at 10kHz keeps the peak current under 2A but gives a fairly decent approximation:

$$I_{peak}=1.772A$$
$$L=\frac{V}{\frac{di}{dt}}=\frac{V_{bus}}{\frac{I_{peak}}{\Delta t}}=\frac{2}{\frac{1.772}{\frac{1}{40000}}}=28.2*10^{-6}=28.2\mu H$$

That's about 6% error, which can likely be attributed to the unpowered loss through the resistor (?). At least I know we're not off by an order of magnitude or two.

Okay, here goes nothing... going to try to get the control loop to pulse a square wave through the motor by toggling between phase A high and B/C low, and B/C high and A low.

- Going for control loop of 40kHz and square wave of 10kHz
- Aaaand getting `nFAULT` from DRV8323. Not a big surprise, but checking to see what's going on
  - I suspect it might be because I'm not in release mode, which means toggling the timer hardware may not be fast enough

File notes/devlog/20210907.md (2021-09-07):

# Heaps and heaps of heaps

Back at it. Ended up spending waaay to much time tracking down yet another `ID10-T` error
- After implementing the heap (I'll get to that in a bit), I noticed I was unable to send CAN messages to the board
- Git bisecting showed that it was due to a specific commit, but I couldn't, for the life of me, figure out what it had to do with FDCAN
  - ... turns out it had nothing to do with it at all, actually.
- I tried to put a breakpoint into the main loop inside the `Driver` but oddly it never got hit ?!
  - The `ADC1_2` interrupt was firing alright. I've got a simple bit-banged GPIO LED indicator with a few `nop`s between on and off, and it was turning on fine
  - It did seem a bit brighter than normal so I probed it: Ayup, duty cycle was like 40%, going at ~1MHz. Wat.
- Looked like `ADC1_2` IRQ was continuously firing at ~1MHz
  - It _should_ have been sync'd to `TIM1` which is firing at 40kHz. This usually means that I'm not clearing an IRQ flag
  - ... but I was? `clear_pending_irq(device::Interrupt::ADC1_2);` was literally the first line of the interrupt handler. What gives?
- Spent like three hours tracking it down
  - Did I miss-configure the `TIM1` trigger? Nope
  - Was the IRQ flag not being cleared in the `NVIC`? Nope
  - Was I doing something wrong in the new `InterruptBLock` synchronization primitive? Not as far as I could tell
- Finally tracked the 40kHz->1MHz cause down to a single, seemingly-innocuous line: `let _foo = hardware.current_sensor.sample();`
  - Wat. Oh... yeah, that'll do it:

    ```rust
    // Clear the EOS flag from ADC1, what we're using to trigger the control loop interrupt.
    // Note: `clear()` is a bad name, since it doesn't clear the _bit_, but clears the _flag_ by
    // writing a 1.
    sensor.phase_a.isr.modify(|_, w| w.eos().clear());
    ```
  - Turns out while I was acknowledging that the interrupt had been handled to the `NVIC`, the `ADC1` peripheral continued to signal to the `NVIC` that there's an "end of sampling" interrupt that needed to be handled

Phew. Now back to the heap Wait, heap? Aren't those bad in embedded systems?
- Yes and no. [Fragmentation](https://www.embedded.com/dynamic-memory-and-heap-contiguity/) is problematic on memory-constrained systems, but there are [strategies to deal with it](https://www.iar.com/knowledge/learn/programming/mastering-stack-and-heap-for-system-reliability/)
- Rust's core/`no_std` libs don't support heap allocation out of the box
  - This is generally A Good Thing:tm:, since you can be sure any library you depend on won't magically start allocating stuff and eating precious memory
  - That also means essentially everything has to have a `'static` lifetime
- For example, say you wanted to have a `ControlLoop` `trait` where any class that implemented it could be swapped in and executed during the 40kHz control loop:

  ```rust
  pub trait ControlLoop: Send + Sync {
      fn commutate(&mut self, current_sensor: &CurrentSensor<current_sensing::Sampling>)
          -> LoopState;
      fn finished(&self) {}
  }
  ```

  - Theoretically all you'd have to do is `impl ControlLoop` and then pass it around as a `dyn ControlLoop`, but therein lies the problem: trait objects are [fat pointers](https://guihao-liang.github.io/2020/06/06/fat-pointer)
- There are (currently) [a few ways](https://stackoverflow.com/questions/26212397/references-to-traits-in-structs) to store trait objects in structs for later use:
  - References: requires lifetime propagation, and if you store them in a global `static` object all fields inside must be `'static` since you [can't declare a custom lifetime on one](https://stackoverflow.com/questions/40053550/the-compiler-suggests-i-add-a-static-lifetime-because-the-parameter-type-may-no). In other words, [_"Every type has an implicit `'static` lifetime if no generic lifetime is specified"_](https://stackoverflow.com/questions/59773865/can-static-be-placed-along-the-struct-declaration)
    - Aside from some terribly `unsafe` code that introduces quite a bit of UB and makes some assumptions about the format/layout of both the fat pointer and the vtable, there's no easy way to get something from main code into an interrupt handler
  - Enums (`enum People { Grandma(Grandma), Son(Son) } ` trick) - Not bad, but not very generic, requires a decent amount of boilerplate, and enum variants don't (yet) have their own types. Overall code smell
  - `Box`es - Simple, but requires heap
  - Transforming a `FnMut` into an `fn`, but that precludes capturing any variables inside of the closure
- Changing the commutation loop on the fly is my main use case: swapping between calibration, encoder testing, inductance/resistance measurement, etc on the fly via FDCAN commands
  - Since the scope of the trait object use case is small, going to run with the [alloc-cortex-m](https://github.com/rust-embedded/alloc-cortex-m) crate
  - Unfortunately it just uses a [linked-list allocator which is pretty prone to fragmentation](https://github.com/rust-embedded/alloc-cortex-m/issues/36), so I'm going to monkey-patch in a [Two-Layer Segregated Fit heap](https://github.com/yvt/rlsf/tree/main/crates/rlsf)

Onto implementation details

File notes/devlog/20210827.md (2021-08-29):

# It's a mystery

I'll let Jack take it from here...

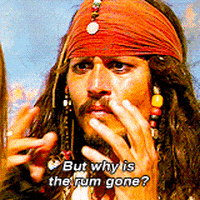
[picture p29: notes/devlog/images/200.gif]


`s/rum/noise/`

I cannot, for the life of me, reproduce the noise on the current sense B line. Only thing I can
think of is that the 2.84MHz noise was coming from some switching going on in the power supply at a
certain level...?

Idea for control loop: `Some<Fn(...)->ControlStatus>` for control loop callback, where
`ControlStatus` is enum `Continue` or `Finished`. That way we can set the control loop temporarily
e.g. during calibration, and have the control loop stop itself
- This would likely require a call to something like:
```rust
driver.with_control(|...| {
  // Do whatever with the controller here
  if done {
    return Finished;
  }
  Continue
}, Some(|...| {
  // This Optional callback is called when commutation is finished, e.g. to respond over CAN with
  // calibration values, or to clean up any extra peripherals we might have used like TIM16 or
  // something
}))
```

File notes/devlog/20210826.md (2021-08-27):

# Current (non)sensing

Hooray for a new [Riden RD6018 power supply](https://www.youtube.com/watch?v=y_TAnfTYa6I)! (not me :) No more awful 60Hz noise. Still some switching noise in the 60~70kHz range at low frequencies, but that should be okay for now.

Something is a bit off about my current sensing. On the scope I'm seeing pretty rock-solid sense traces between PWM pulses:

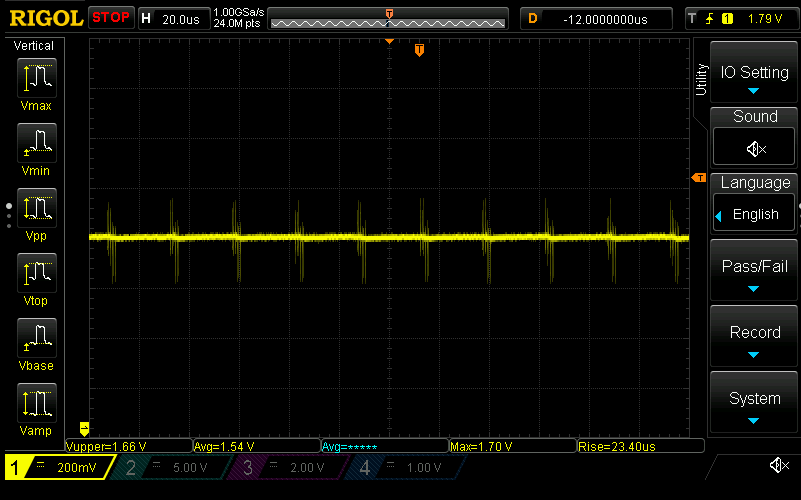
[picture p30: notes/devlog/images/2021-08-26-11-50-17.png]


That's 1.54v on phase A, and from the DRV8323R spec, we get $I=\frac{\frac{V_{vref}}{2} - V_{SO_x}}{G_{CSA}\times R_{SENSE}} = \frac{\frac{3.3}{2} - 1.54}{40\times 0.001}=2.75A$. But the ADC is reading something like -1.371A (???).

I implemented a calibration step during current-sensor bring-up, but maybe I've got a bug there?
- I suspect it might be something wrong in the ADC calculation, like I've got $v_{refint}$ where $v_{refint\_val}$ or $v_{refint\_cal}$ should be...?

Probing around, it looks like - at least initially - ADC1 is spot on. But ADC2 and ADC3 are reading a bit high (0.5% and 2% respectively). Let's look at the affect of ADC1's readings as a function of v_refint:



All the readings are a bit high for the range. Let's see if we can get a sense of how much/where the noise is...
- ADC distribution of 3k samples:

  

- ADC2 looks kinda weird, but seems okay overall
  - Almost looks as if it's not actually 12 bit?
  - Could also be noise on the DRV8323's output lines; possibly inductive coupling in the PCB
- I should look into the DRV8323's calibration routine...
  - Going to try calibrating each CSA one at a time. No difference
  - Going to try calibrating each CSA for longer. No difference
- How about we just sample for longer?

  

  - Weird. I mean the ADC1 looks fine, albeit with a bit of a median shift, but the distribution itself doesn't change
    - Means I can just do an initial offset calibration
  - @skoomadentist from [Amulius](https://discord.me/amuliusengineeringchill) suggests it might actually just be a 10-bit ADC due to the DNL:
    

  - Tried oversampling. A lot better at 4x:

    

    - I don't like losing the 240 samples of the scant 2125 available every cycle. Will try to avoid that if possible
- Let's probe the sense lines
  - Note to self: add a via to probe all current sense lines on the next rev, not just A and C
  - Phase A:

    

  - Phase B:

    

  - Phase C:

    

... Oh. The ADC seems to be working fine. There's something weird with Phase B. Could there be some coupling with the sense lines or something?



Okay, going to ignore the super high frequency noise for now and see if I can get some sane readings.
- Seems like there's some odd dynamics on starting conversion
- Wonder if I have to take the $t_{SET}$ here into account: at 40V/V the time is 1.2us (!)

  

  - Not clear what $V_{O_STEP}$ is in this case. Guessing? If the $V_{sense}$ voltage jumps half a volt, this is how long it'd take the amplifier to get to the right output.
- So it looks like the most accurate calibration is _not_ to use continuous, but to trigger a calibration manually via software
  - This is analogous to the ADC idling until `tim_trgo2` happens. I don't have a good scope of this happening, but given I see a ~10-15mV difference in the `SENSEx` lines between continuous and single-shot mode I'm fairly confident this is what's happening.

_Side note: The 2.84/2.85MHz noise is really annoying, but something tells me it's due to the new switching power supply I'm using. Will look into that later_

  - With this setup I'm now seeing <= 100mA of noise, usually right around ~50mA centered around zero
  - Occasional spikes into ~200mA, but oversampling in the controller - something I'm learning about in [control theory boot camp](../control%20theory%20bootcamp/../control%20theory%20bootcamp/part01.md) - can likely make this level of noise pretty much moot.
  - Pretty happy overall now with the phase current senging. Still kinda leery about that noise on `SENSE_B`, but can live with it for now.

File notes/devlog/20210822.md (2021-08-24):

# Crappy power supplies, part deux

Had a shower thought this morning that the noise might be due to my power supply just EMR radiating 60Hz
noise, but nope, moving it away didn't help. Just probed the outputs and there's some serious 60Hz
noise coming through (tens-hundreds of mA, scope can't go that high).

Okay, new power supply ordered. Hopefully that will fix the noise on the current sense resistor and
main power supply. If not... well, we'll worry about that if (when) it happens.

In the meantime, can concentrate on the PI controller design, and just assume a few of the
parameters for now until I can actually measure 'em.

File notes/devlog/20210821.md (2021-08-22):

# Proper ADC reading

I've gotten pretty far just using the raw ADC peripherals, but I think it's time to make a small current sensing wrapper that has access to all the ADC bits we need.

I keep trying to re-invent the HAL. I see useful Rust-isms, but I really gotta focus on getting the BLDC control done before going all Rusty...

Okay, got ADC up and running. All you have to do is `current_sensor.sample()` and it'll return an `f32` voltage for `v_bus`, and a _calibrated_ phase currents for 1/2/3. Needs some cleaning up, but good enough for now.

I'm seeing fluctuations on the phase currents of around 0-0.18A. In the grand scheme of things this shouldn't matter too much, but I wonder how much more accurate I can get (need?). Let's try bumping the sampling period up a bit.

Not a whole lot of difference going to 12.5 samples. how about 24.5... That gets it down to about ~0.06A, which is actually a lot better.
- Unfortunately that lowers our available control loop time from 12.5uS to 11.6us. Not too bad of a loss, but still, when every microsecond counts...
- I wonder if this can be avoided by only sampling for a longer time period during calibration...? Nope.
- This may _also_ be due to the fact that my switching power supply doubles as a [vuvuzela](https://www.youtube.com/watch?v=bKCIFXqhLzo) for all the noise it makes...

***sigh***

Pretty sure I just need a better power supply. Here's a _grounded_ probe of `sense_a` line:



And yup, the rail line looks like that too. Just can't get my Rigol scope to get a good a pic of it, but it's definitely there. And when you're measuring ~10mVs or less that counts. That's a good +/- 40mV

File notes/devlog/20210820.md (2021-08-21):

# Measuring inductances

So figured out why my current loops were all wonky. Turns out my [loop variables](./20210819.md)
weren't being handled correctly. :facepalm: On the plus side, my current measurements look somewhat
close to my [Falstad
simulation](https://www.falstad.com/circuit/circuitjs.html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)
when toggling at 20kHz (yellow trace is current):



And the current measured across the resistor, toggling phase A high B//C low, then vice versa:



So trying to generate a square wave now, but it looks like I'm losing a variable inside of a closure
somewhere...
- I set `let mut sign = -1f32` before the control loop, and do a `sign = -sign` to invert it every iteration
- Oddly, by the time it gets into the loop, `sign` is `0` ?!
- I wonder if this has to do with how I'm munging the callback in the `IRef`, potentially blowing away the vtable
- Okay, initially the memory address of `sign` is `0x20017fcc`, and inside the loop it's... `0x20017fd4`. That doesn't seem right
- But if I assign it to a `static mut`, the location goes back to `0x20017fcc` as expected...???
- Sounds suspiciously like UB
- Okay, well I guess for now I'll

And we've got a "triangle wave". At least it matches with the sim at 10kHz:





And at 5kHz (note: had to turn it down to 12V here since we're driving a bit more current than I'm comfortable with here):





Getting the inductance measurement up now. Headphones = required... the 10kHz whining is _really_ annoying...

Beginning to realize I don't particularly like the API I'm using for the different commutation loops... I'm imagining something new along the lines of `.commutation(fn_ptr)` or something along those lines.

Getting current sampling timing going with the square wave generation. Need to coordinate sampling time with the end of the pulse. That required tweaking `TIM1[CH4]` to be the _inverse_ of the other channels; when others go low (end of PWM signal and corresponding current surge during the square wave), CH4 goes high.



Yellow pulse is winding voltage (what induces the current on across the resistor), and blue is when sampling has finished and we've entered the ADC interrupt handler and pulsed a GPIO.

Actually, that seems a bit _too_ good to be true. Putting the trigger point at the _exact_ inverse signal of the PWM means there's about ~356ns between the falling edge and the rising one of GPIO pulse. Yeah, 6 clock cycles is ***way*** too fast.

Wait, no it's not; [PEBKAC](https://en.wikipedia.org/wiki/User_error). Turns out at 170MHz each clock is 5.88ns, not 58 :zany_face:. In that case it's about 60.5 cycles between the beginning of the sampling and the end of conversion, and given we're running with an ADC freq of $F_{core}/4$ and conversion takes 2.5 ADC cycles, that results in $356ns * \frac{4}{170e6}\approxeq15\ ADC \ cycles$. That's _just_ enough time to sample and get into the interrupt handler.

But wait, key point: that's measured from the _phase_ voltage, not from the PWM signal. The $\Delta t$ between the PWM edge and the GPIO edge is... _drumroll_... about 720ns:



It takes 500ns to convert:



That leaves us with 220ns to distribute. At 5.88ns per clock cycle, that gives... 37.4 clock cycles between EoC and GPIO pulse. That's about 30 clock cycles shorter than I've been able to record before, so taking into account the slew time of both the DRV gate drive output and the FETs, we'll probably need to delay the measurement by at _least_ 30 clock cycles.

More on that tomrorow :sleepy:

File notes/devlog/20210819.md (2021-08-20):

## The case of the sleepy DRV

Solved the DRV wakeup issue! **TL;DR:** Rust made my program run too fast



Well that was an odd bug to fix. DRV worked fine in debug mode but didn't want to wake up in release mode. Probing SPI lines showed the MOSI line transmitting data just fine.

But what was strange was the first frame's MISO line read correctly, but subsequent frames - including writes - just showed 0s, which was super odd.

I put in a blocking_sleep_us(20) in between each individual DRV register update (consisting of a read/write operation pair), and suddenly every read worked, but the update wasn't returning the register's value correctly.

Turns out even at 5MHz SPI clock the time between pulses was longer than the time between frames.

Looking at the DRV data sheet:



Huh. I guess my register updates were going so fast in release mode that the combination of nSCK pin going HI-Z (in hardware mode) and the 1k pullup on the DRV_CS resulted in the DRV_CS pin not staying high for long enough between frames

I put a 1us sleep before each read/write (I'm not polling during the control loop, so blocking is fine), and bingo, works in release mode now!

Now that I look at it, I should probably move the calibration/startup code into the DRV struct. Let's do that.

Done. Man, rust is _intuitive_. Not only did the type-state pattern help here, but I also managed to remove a generic within `Controller` as well, since it now requires a `Drv8323rs<Ready>` to finish startup, which can only be created after `drv.calibrate()` call completes successfully. Neat!

Okay, going to try the inductance measurement again in release mode... No more faults!
- But the waveform I'm generating doesn't seem to change with the control loop. I suspect there's something ... oh wait. I'm not incrementing the state counter... ***sigh***

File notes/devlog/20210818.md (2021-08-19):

## Release mode

Seeing some weirdness in release mode: looks like the DRV chip doesn't want to wake up. I'm seeing execution being blocked by `block_while! { spi.sr.read().bsy().bit_is_set() }` when trying to read a DRV register.

Hm, that's annoying. Seems like sometimes it gets stuck there, sometimes it continues on...?

Okay, fixed one issue where I was polling SPI too quickly after turning on the DRV, which caused the `BSY` bit to hang waiting for the reply from the DRV.

I really need to move the systick timer into a globally available instance; passing it around seems like a bad idea.
- Global singletons are bad, m'kay? But in this case since it's blocking we should be okay.
- Oh, wait. If I don't declare it `pub` and instead use it from a wrapper, then there's absolutely no way for it to escape
- Rust never ceases to amaze me 

Okay, so doesn't seem like it's a wake-up issue. I've sprinkled `blocking_sleep_us` everywhere I can and can't seem to coax the DRV to do anything as yet.

Blocking sleep doesn't seem to be an issue anymore, since sleeping for $1000\mu s$ results in a sane sleep time: 

The timer does appear to be firing on schedule (should be ~470.5ns):
E

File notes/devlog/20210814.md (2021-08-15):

# PID loop

Trying to understand/calculate the values I'm going to need. [Ben's are commented but unclear](https://github.com/bgkatz/motorcontrol/blob/2fa6cabbebcb19efb9d6b2dd0f59edc3537ad64f/Core/Inc/hw_config.h#L55)

Figured out the $I_q$ and $I_d$ inductances just like [Ben
did](https://build-its-inprogress.blogspot.com/2016/02/motor-control-progress-working-hardware.html)
- Used a 10$\Omega$ resistor and a rechargeable battery (DC meter switching introduced way too much
  noise) and set positive to phase A and grounded phases B&C
- Measured max voltage, then measured 63% of that value and set the trigger on the scope there
- Turned the motor until I got the least amount of rise time to time constant $\tau$: 6.8$\mu$s
- That translates to $L=\tau\cdot R=6.8\times10^{-6}\cdot\left(10\Omega +\frac{1}{\frac{1}{0.200\Omega} + \frac{1}{0.200\Omega}}\right)=6.8\times10^{-6}\cdot10.3=70\mu H$
- $I_d$ and $I_q$ are assumed to be the same since this is a surface permanent magnet motor (induction motors need more care)

## System model in Continuous and Discrete time


- Continuous time frequency response $\frac{I(s)}{V(s)}$ has the transfer function $\frac{I(s)}{V(s)}=\frac{1}{Ls+R}$
  - Bode plot

    
  - First order low-pass filter with a DC gain of resistance $\frac{1}{R}$
  - Cutoff frequency of $\frac{R}{L}$
- Converting to discrete time, and design controller there
  - Through algebra $\frac{U(z)}{E(z)}=\frac{\frac{1}{R}\left(1-e^\frac{-RT_s}{L}\right)}{z-e^\frac{-RT_s}{L}}$
    - $T_s$ is sample time in seconds (0.000025 for 40kHz loop)
    - Discrete bode plot

      
      - Note that the phase drops to -180 at $\pi$ radians per sample

## Designing the controller
- Discrete-time PI controller: $\frac{U(z)}{E(z)}=k\left(1+\frac{ki}{z-1}\right)$
  - Has a pole at $z=1$ and a zero at $1-ki$
  - $k$ is high freq. gain
    - Changing $k$ only changes the loop gain
    - Changing $ki$ only changes the zero location
    - This is contrary to the typical parallel PI expression

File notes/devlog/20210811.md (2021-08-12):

# Moving data into ISRs

Okay. Trying to Get something up and running that moves information from the main loop (FDCAN
message processor) safely inside the control loop interrupt handler.

- Got the transaction up and running
  - Not exactly the cleanest API; will have to rethink later.
  - Ah, much better: hide the fact entirely from the end user. Instead, create the `BufferedState`
    inside the run function, allowing the user to pass in whatever state they want.
- Now I just have to figure out how to get into the control loop callback from the interrupt...
  - [m4vga has an interesting
    approach](https://github.com/cbiffle/m4vga-rs/blob/a1e2ba47eaeb4864f0d8b97637611d9460ce5c4d/m4vga/src/rast/mod.rs#L120)
    using something called an `IRef`, which I assume is short for `InterruptReference`
    - Looking it over it's not quite what I think I need. Cliff's version ends up loaning a
      reference for the duration of a `scope` closure. This `scope` is actually the "main loop" of
      the program,
    - It is kinda neat how he uses ` loop { vga.sync_to_vblank(); ...render frame... }`, and behind
      the scenes `sync_to_vblank()` blocks until the interrupt is called... I think?
    - [Yup!](https://github.com/cbiffle/m4vga-rs/blob/a1e2ba47eaeb4864f0d8b97637611d9460ce5c4d/m4vga/src/driver.rs#L144)
      Neat. Will have to try that later. For now just being dumb with a `SpinLock`
  - Nevermind, `SpinLock` won't work: callbacks are [fat pointers](https://guihao-liang.github.io/2020/06/06/fat-pointer)
    - `IRef` above does some [gymnastics](https://github.com/cbiffle/m4vga-rs/blob/a1e2ba47eaeb4864f0d8b97637611d9460ce5c4d/m4vga/src/rast/mod.rs#L174) to stuff a callback it into a `Cell<(usize, usize)>`
  - Okay, okay, fine, I'll butcher `IRef`
- Okay! So we've got a comms handler and a commutation handler up and running
  - Good to know that you can now put `#[interrupt]`s in their respective files
  - Man, the main program is now pretty concise...
- Next up: moving peripherals into the control callback
  - Not sure I like all the indirection here, but _did_ get saved by Rust yet again
    - Turns out I was holding onto the lock for `COMMUTATION_SHARED`, which includes the `tim1`
      peripheral. When I enabled the timer, the interrupt fired and caused a panic. Score one for Rust!
- So now I've got all the pieces piped into the control loop. Now on to FOC!
  - This is the scary part... I know I'm gonna blow something up :/
  - Okay, so looks like we need two PI controllers (no D?), one for $I_d$ and one for $I_q$
    
    - (from [Teaching Old Motors New Tricks Part 2](https://www.youtube.com/watch?v=VI7pdKrchM0),
      highly recommended!)
    - It's kind of interesting that the desired $I_d$ always 0. If it's measured to be nonzero, the
      control loop will generate a corresponding correction on the output $I_d$
  - Working on my [FOC transforms](../../notebooks/foc_transforms.ipynb) notebook which I think kind
    of emulates Ben's [motor modeling scripts](https://github.com/bgkatz/motor-modeling)

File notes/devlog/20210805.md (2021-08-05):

## Current sensing, round 2

- Okay, so gotta get current sensing running correctly
  - Reading 1.81V on the SOA line, regardless of whether the phases were actually going ...?
  - OH. Wait. I think something's messed up with my blocking sleep?
  - Ayup, broken SysTick. Note to self: Timer's don't reset themselves
    - SysTick was keeping the previous countdown value from the last time the timer was used
    - It counts _down_, which meant that when I was trying to sleep 200us for the ADC calibration it was actually only sleeping for <= the ~20us from the ADC power up
    - Huh, I'll bet that's the cause of why the DRV didn't work in Release mode: wasn't getting enough time to start up...
      - Nope, not the case :/
  - Now that the DRV is properly sleeping for 200us (really required only 100us), current sense amplifier values are spot on.
- Hand-calculating the DRV current now with an SOA reading of 1.71V for a duty cycle of 1.88%
  - $I=\frac{\frac{V_{vref}}{2} - V_{SO_x}}{G_{CSA}\times R_{SENSE}} = \frac{\frac{3.3}{2} - 1.71}{40\times 0.001}=\dots -1.5A$
  - At a gain of 40, that means every hundredth of a volt corresponds to 0.25A
    - TODO(blakely): Might have to tweak that down to 20
- Finally, reading via ADC at the above settings gives us a reading of... 0x7f6
  - That doesn't make sense. That's a reading of about 1.65V or... nothing.
    - I'm only sampling for 2.5cycles, so let's bump that way up and see if that helps? Nope
  - Okay, I'm very likely sampling the wrong pin/channel. Double-checking
  - Oh, duh; it's not overwriting.
  - Okay, now actually reading. Seeing ranges of 0x82a-0x82f, corresponding to a range of 0.99107A-1.092A, or a noise of about 100mA. Not great, but not bad
    - That was with 640.5 clock cycles. Bringing it back down to the 2.5 gives... 0x82d-0x834
    - 1.051A-1.1931A is a bit higher (?)
- And bingo! Have current sampling!
  - Validation:
    - Reading adc:

      _(from STM32G474 datasheet)_

      $V_{ref\_calib}=3.0$
        - _Reference value used during testing at chip plant_

      $val_{refint\_calib_data}=0x67B$
        - _Value stored at `0x1FFF 75AA - 0x1FFF 75AB`_

      $val_{adc\_vrefint}=0x5DF$
        - _Value read from ADC that reads the $V_{refint}$_

      $val_{adc\_current}=0x82d$
        - _Value read from ADC that reads the SOA pin from the DRV_

      $V_{SOA\_ adc}=\frac{V_{ref\_calib} \times val_{refint\_calib_data} \times val_{adc\_vrefint}}{val_{adc\_current}\times 2^{12}}=\frac{3.0\times0x67B\times0x82d}{0x5DF\times4096}=1.692V$

      - Measured by scope: somewhere between 1.69-1.70V. Nailed it :thumbsup:

    - Converting to Current:

      $G_{csa}=40$
        - _DRV gain_

      $V_{vref}=3.3$
        - _Measured via scope_

      $V_{SOA\_ adc}=1.692V$
        - _From above_

      $R_{sense}=0.001\Omega$

      $I_{phase}=\frac{\frac{V_{vref}}{2}-V_{SOA}}{G_{csa}\times R_{sense}}=\frac{\frac{3.3}{2}-1.6945}{40\times 0.001}=1.05A$
        - So about 1.0A on the phase

    - Simulation: Assuming a single phase has $R_{phasex}=180m\Omega$ (based on [this Aliexpress listing](https://de.aliexpress.com/item/32866434951.html))

      $V_{pulse}=24$
        - _Bus voltage_

      $Freq_{pwm}=40kHz=25000ns$

      $t_{pulse}=328ns$
        - _Measured from edge to edge across FET_

      $D=\frac{328}{25000}=0.01312$
        - _Actual duty cycle_

      $V_{dc}=V_{pulse}*D=24*0.1312=0.31488V$

      $I=\frac{V}{R}=\frac{V_{dc}}{R_{phasea} + \frac{1}{\frac{1}{R_{phaseb}}+\frac{1}{R_{phasec}}}}=\frac{0.31488}{180 + \frac{1}{\frac{1}{0.180}+\frac{1}{0.180}}}=\frac{0.31488}{0.180 + 0.90}=\frac{0.31488}{0.270}\approxeq1.166A$
  - So off by approximately 100mA from ideal sim
    - Considering how many sources of error there were along the way, I'm pretty satisfied with that reading.
    - Also likely that the actual phase resistance is slightly higher. If we bump it up by $20m\Omega$ to $R_{phasex}=2000m\Omega$ we get $I=1.0496$.
    - Note that the biggest source of error was the ADC conversion, which seems to be pretty darn spot on to what I can probe

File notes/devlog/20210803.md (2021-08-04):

- Going to get remaining ADCs up and running, then do proper Rust ownership passing
  - Any HAL that wraps these peripherals needs to make clear if/when it's mutable. Right now I can `let adc1 = &self.mode_state.adc1;` and still modify it via `adc1.modify(|r,w|...)`
  - Okay, getting sane values on all current senses (low ~10s of millivolts, which seems sane)

Well, I've been putting this off for a while for fear of burning the board. Here goes nothing, going to try to sense the current by toggling one PWM at very low duty cycle.

- First, need to ensure the DRV is configured correctly
  - And calibrated. Can't forget to do that.
  - Ben left his gate drives at 1A. Might want to actually change that for the specific mosfets:
    
  - Hm. Running into a borrowing issue again with SPI:
    ```rust
      error[E0382]: borrow of partially moved value: `self`
      --> bldc/src/driver.rs:851:13
        |
    817 |             drv8323rs::new(self.mode_state.spi3).enable(|| gpioc.bsrr.write(|w| w.bs6().set_bit()));
        |                            -------------------- value partially moved here
    ...
    851 |             self.blocking_sleep_us(200);
        |             ^^^^ value borrowed here after partial move
        |
        = note: partial move occurs because `self.mode_state.spi3` has type `stm32g4::stm32g474::SPI3`, which does not implement the `Copy` trait

    For more information about this error, try `rustc --explain E0382`.
    ```
    - That's because I do configuration of the SPI inside of the `Drv8323rs::new`, and I pass it ownership of the SPI peripheral:
    ```rust
    pub fn new<'a>(spi: device::SPI3) -> Drv8323rs<Sleep> {
      // SPI configured
      Drv8323rs {
          spi,
          mode_state: Sleep {},
      }
    }
    ```
    - Simple enough: don't require `&mut self` for `blocking_sleep_us`; just use the wrapped function directly
- Okay! So have the DRV up and running (and hopefully calibrated)
  - TIM1 PWM is set to 0, so there really shouldn't be any current flowing
  - Have to be _really_ careful probing now that the DRV is enabled...
  - Getting 0x8C1, 0x86C, and 0x85b on all three ADCs. So they're working... kind of?
    - Wait, that might make sense if there can be negative current on one of the phases.
    - Seeing 1.8V on the SENSE_A input
    - Vref on DRV is rock-solid at 3.3V
    - Specs from Datasheet:

      

  - Okay, so that kind of makes sense. Going back to [a few days ago](./20210730.md) when I was getting $V_{refint}$ working, the internal calibration was 0x067B@3.0V

    
    - $V_{channel}=\frac{3.0\times0x5DF\times0x8C1}{0x67B\times4096}=1.812V$
    - So converting that over via the DRV's bidirectional sensing equation:

      
    - $I=\frac{\frac{V_{vref}}{2} - V_{SO_x}}{G_{CSA}\times R_{SENSE}} = \frac{\frac{3.3}{2} - 1.812}{40\times 0.001}=\dots -40A?!$

___Minor heart attack___

- Well, it did... something. A pretty loud whine came out of the coils, the power supply started current limiting at 334mA, and I shut off the power supply in panic. :scream:
  - Gonna take a break for a bit :sweat_smile:
- Okay, so it only happened when I put a breakpoint after the DRV enable, but _before_ the timer kicked off
  - It looks like as soon as the MOE bit is set the PWM signal rails to 3.3v,which in turn forces the DRV to open the high side, causing current to rush through the windings
  - I suspect the screaming I heard was actually due to the PWM current limiting. Good thing I didn't go too high with that...
  - Going to turn off the DRV and investigate the timer a bit to make sure that can't happen again.
- Took the lazy way out: don't enable the main outputs until after the timer has started :P
- But hey, the FETs are working!
  
  - Note the divisions: the blue is PHASE_A, yellow is PWM signal
  - There seems to be about ~45ns of jitter on when the FETs actually turn on. I assume this is somewhat normal?
  - The lag between the rising PWM edge and FET turn on is about 250-300ns. Pretty slow...
    - Wonder if it has to do with the deadtime insertion?
- Also it appears release mode doesn't play nice with the DRV startup code. Will have to look into that
  - I suspect that it's optimizing something away in `bitfield.rs`

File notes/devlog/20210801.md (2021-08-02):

# Getting Current sense amps up

Today's goal: Trigger CSA ADCs for conversion via TIM1_CH4

- Man, I really need to refactor these ADCs into their own structs... but will do that later.
- Trying to determine whether we need "continuous" or "discontinuous" mode. I _think_ we want
  discontinuous according to this figure:
    
  - Though then again maybe not, since discontinuous seems to be able to sample a subset of the sequence.
  - And even though we want to trigger on external signals, that's _technically_ not an _injected_ read
- Okay, have ADC1 started. Now to set TIM1_CH4 to output `tim_trgo2` if we can.
  - That was surprisingly easy? Just required setting `mms2` to _"Compare - tim_oc4refc signal is used as trigger output(timtrgo2)"_ (`0b0111`)
  - Well, at the very least the EOS and EOC flags are set, as well as overrun; expected, since I don't have the interrupt for the ADC set up yet
    - Though I _do_ have the one for TIM1 still going. Gotta fix that
- And done! Now triggering on ADC EOS
  - Profiling now (release mode): bit banging the LED GPIO from the interrupt handler
  - Triggering by CH4 at 2124/2125 ARR; 99.95 duty cycle, so effectively right in the middle of the hardware-enforced deadtime
    
  - Looks like it's triggering at about 888ns after the falling edge. Calculating the center of the dead time:
    
    - 480ns, so triggered just about 240ns into dead time (slightly before)
  - So total conversion + interrupt handler entry + instruction to turn on GPIO: 888-240=648ns, or about 110 core clock cycles
  - Seems a bit on the long side...? Let's do the math
    - ADC sampling rate: 170Mhz/4 = 42.5MHz.
    - Sample duration: 2.5 _ADC clock cycles_ (not core!)
    - Conversion time: 12.5 ADC clock cycles
    - 15 clock cycles at 42.5MHz is 352ns, or 60 core clock cycles
    - Means getting into the interrupt and finally toggling the GPIO takes 110-60=50 core clock cycles
- TL;DR: 110 cycles, or about 647ns between PWM pulses, sampling the ADC, and getting into the core control loop interrupt handler
  - Not _too_ bad. At a 40KHz control loop, that's 4250-110 = 4140 clock cycles to do the control loop
  - In other words **we've got 24.353us to work with for control**
  - And now that I think about it, we might have a little bit more: I think the interrupt handlers are executing out of flash
    - Can probably speed up quite a bit by putting them in either SRAM or CCMRAM
    - Can do this in Rust via `#[link_section = ".$LINKER_SECTION"]`

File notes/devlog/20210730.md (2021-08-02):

## More ADC work

So after sleeping on it I'm pretty sure it has to do with the input impedance and ADC capacitance. We're just not letting the input cap charge up fast enough to sample at 2.5 cycles. Ramping up to ~47.5 seemed to make it go away. The VBus shouldn't change all _that_ much, so I suspect that it should be okay keeping it at 47.5 ADC samples.

- Settling on 47.5 ADC samples. Seems consistent enough
- Bingo! Got continuous conversion mode up and running
  - Looks pretty linear:

    
  - Seems like it's roughly 76.345 bits/V
  - Offset of 11 though, wonder if that affects much?
  - 3.3v/Vref rail is spot on though
- Okay, digging into this the old-fashioned way: breakin' out the multimeter
  - At 24.01V on the bus, I'm reading 1.432V at the sampling pin. Calibrated ADC reads 0x733 (1843)
  - That gives us `1843/4096 * Vref = 0.450 * 3.3 = 1.485`, off by 0.053. Odd.
  - Oh, wait. Without the ADC on it's at a rock solid 1.5V. I'll bet there's Vdroop due to the sampling cap!
    - Ayup; bingo: RMS voltage due to the initial droop due to charging the sampling cap is probably the cause of the mismatch:

      
  - What to do about it though... can't slow down the ADC sampling since one of the phase current senses is on ADC, which is tied to the slave clock that drives ADC[345]
    - TODO(blakely): Potentially add a V1.1 add a cap to the ADC sampling line?
    - From AN2834:

      
      - Note the issue about cycling, which may stress the cap
  - Okay, well, it's about as good as it's going to get; jacked up the sampling time to 640.5 samples. Doesn't need to be all that real-time; lithium batteries are pretty good about handing current spikes without sag
- Gonna try to see if I can read Vref reading on ADC5. Might as well
  - Very similar to ADC4. Really should wrap this up in a HAL
  - Well that was easy
  - Looks like calculating it based on the internal Vrefint and the factory calibrated value (located at `0x1FFF75AA`) gets me even closer: looks like the battery sample is now at 1.492568V, which after the 16x increase brings us within half a percent. Good enough for me :thumbsup:

- Okay, now to do ADCs for current sensing
  - Looks straightforward enough:
    
  - Going back through the timer documentation to see exactly what signals are triggered and when
    - Aha, looks like the ADCs can _only_ be triggered by `tim_trgo2`:
      
      - Though that suggests "such as" vs "only", so might not be restricted to that
    - Well hmph... for TIM1, channels 1-3 are the PWM, channel 5 is the enforced deadtime, and I apparently used channel 4 for an interrupt (not sure why :shrug:)
    - That leaves CH6 for the trigger reference point; importantly it's on ***falling edge only***
    - Looking at the [TI app note](https://www.ti.com/lit/ug/tiducy7/tiducy7.pdf?ts=1627708655954) for current sensing:
      
    - Need to make sure we're sampling at the right point
  - Hey Timmay, ***STAHP***: this is premature optimization
  - Just going to sample in the middle as a compromise.

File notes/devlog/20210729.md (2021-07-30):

## SysTick

Need a blocking wait for the ADC calibrations from [yesterday](./20210728.md). Will try to use SysTick instead of sacrificing a timer.

- I don't want to pay for the overhead of an interrupt every tick and want to see if we can get microsecond resolution
  - Got the peripheral up and running, but seems mis-calibrated; 5e6 micros lasted less than a second...?
  - Oh, turns out I was calculating it assuming the timer was counting micros, not clock cycles
- There's a bit of subtlety to blocking for microseconds
  - SysTick is 24 bit, which means the maximum number of ticks before we hit the wrap bit is 2^24
  - If we want to sleep for something like 1s, we need to account for multiple loops
- And it works!

## Back to the ADC
- Okay, getting somewhere. Looks like I can get it into calibration mode but... it gets stuck there
  - Usually when this happens it's because there's some clock domain that's not turned on or messed up
  - Datasheet suggests max ADC freq is 60MHz for single adc, or 52 for all ADCs in single-ended mode:
    
  - 170Mhz / 4 gives about 42.5MHz, which should be fine for my purposes
  - Aha, yup! Now that `ADC345_COMMON[CCR]` has the right clocks, calibration finishes.
- Beginning startup
  - Kinda odd that you have to write 1 to `ADRDY` to clear it, but whatever :zany_face:
  - And we're running!
- Okay, now to channel setup
  - Looks like we need to use "injected" mode, since we're going to be (eventually) using an external trigger
  - Well, now that I think about it VBAT doesn't need to be triggered... might leave that for later.
    - Yeah, looks like the [application note](../../third_party/st/documents/cd00258017-stm32s-adc-modes-and-their-applications-stmicroelectronics.pdf) suggests single-channel continuous mode is for "monitor[ing] a battery voltage"
  - Sounds like you can set an arbitrary order of sampling. For now will just set single channel in `ADC_SQR1`
    - Have to make sure to set `ADC_SQR1[L]` bits to tell it how many channels we're converting (should be just 1)
  - Setting sampling time to 2.5 ADC clock cycles @42.5MHz, so ~53ns sampling time
    - Note that is is only for fast channels. Slow channels seem to need a bit more time (2x sampling time)
    - ADC4>IN3 seems to be a fast channel, so I think we're good
      
- Looking at the differences between regular and "injected" modes
  - IIUC both support hardware-trigger starting of conversions (?), and the only real difference is that "injected" J* registers are only useful if there's a regular conversion going on that needs to be interrupted...?
  - [App note](../../third_party/st/documents/cd00258017-stm32s-adc-modes-and-their-applications-stmicroelectronics.pdf) has this to say about injection mode: _"This mode can be used to synchronize the conversion of channels to an event. It is interesting in motor control applications where transistor switching generates noise that impacts ADC measurements and results in wrong conversions"_ (my use case, essentially)
  - But if I'm reading this right, you can do effectively the same thing with regular conversion mode + a HW event from a trigger...?
  - Confirmed by @EdKeyes in [Amulius Discord chat](https://discord.gg/wF3aeWC2): _"It just depends on whether the ADC is already being used for other stuff, since there are only a few of them. But if you have an otherwise idle ADC that can wait for the event, you wouldn't need to inject the channel to get it read."_
- Woo, it's doing ... something? The `DR` register is populating at least
  - 0x53 is... not what I was expecting. Guessing I've got the channel configs wrong?
    - The `SQx` registers have the channel number from 0-18... I wonder if that is off-by-one from within cubemx?
    - Aha! [ID10-T](https://en.wikipedia.org/wiki/User_error) error... [PEBKAC](https://en.wikipedia.org/wiki/User_error#PEBKAC/PEBCAK). Turns out it helps if you _sample the right friggin' channel_... ***sigh*** Note to self: CH1 != CH3
- Okay, so now I've got a "sane" reading. `0x59e` when the crappy Dr. Meter power supply reads 23.8V, and `0x4b6` when it reads 20.0V
  - Comes out to ~0.0164V/div which is way more than I was expecting. Gain error?
  - At least it's consistent? Measured factor differences:
    1) Reading 0x433@18.1: `18.1 / (0x443 / 4096 * 3.3 * 15) = 1.3728`
    1) Reading 0x5AF@24.1: `24.1 / (0x5af / 4096 * 3.3 * 15) = 1.3706`
    1) reading 0x4b6@20.0: `20.0 / (0x4b6 / 4096 * 3.3 * 15) = 1.3723`
  - I wonder if `Vref` is weird somehow? Hope it's not 3.3V*1.371=4.52V...
    - Okay, so probing shows it's 3.3V exactly. Thank you regulator
    - Probing power supply shows... It's kinda accurate? 24 on the display shows 24.06V with a multimeter
      - That's... really surprising given how craptastic the supply is, but hey, can't complain!
    - So now going to probe the voltage divider. Maybe it's not 15:1 like expected?
    - Probing the Vbat suggests it's something like 1.3 volts. That's waaay lower than expected.
      - The Vref is 3.3 on the dot, and the 24V rail is as well. Maybe the resistors are craptastic and well outta spec?
      - That's like a voltage divider of 18.46, not 15
    - Woah, wait, if I set the sampling period to 640.5 ADC clock cycles, I get a _completely_ different reading: 0x735
- Probing the Vbat line now to see what's goin' on
  - With a sampling time of 640.5 ADC clock cycles:
      
  - With a sampling time of 2.5 ADC clock cycles:
      
  - Okay, that makes some kind of sense. That just goes to show that the sampling rate can be changed. But why does it change the value so much?
  - Wait.. I'm using a voltage divider with a resistance of ~150k as the top divisor. Looking at this...
    
    - ... that seems awfully like I'm way above the resistance limit? I wonder if changing the sampling period to be way longer would allow the internal capacitors to charge
    - Nope, doesn't seem to change anything
  - Only knob that does anything is the sampling time, which gets us within 7.5% of where we're expecting to be
  - I suspect this has to do with the 150k input resistance combined with the super short sampling time
  - Data point for net time: sampling cycle at 2.5 is insufficient 24.5 gets close, and 47.5 is basically there. Definitely has to do with the input resistance.

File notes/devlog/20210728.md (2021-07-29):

## ADCs today

Main goal: get VBus reading reliably via the ADC and written out the FDCAN bus

- Man it's been a while... refresher on ADC selections:
  1) ADC1 = SENSE_A, IN2; PA1
  1) ADC2 = SENSE_B, IN1; PA0
  1) ADC3 = SENSE_C, IN1; PB1
  1) ADC4 = SENSE_BAT, IN3; PB12  (VBUS_SENSE)
  - Hm... doesn't look like it's an AF setting, so maybe all GPIO pins are wired to some ADC channel...?
- Ah, good; had the werewithal to have the VBAT voltage divider set to 15:1, which would put 24V at 1.6V, which is right in the middle of the ADC.
  - Assuming I'm using all 12 bits, it looks like I've got `3.3*15/4096=0.012` volts/bit.
  - Nominal 24V on this revision, which brings it down to 1.6V on the sense pin, right in the middle-ish of the 3.3V Vref range
- TODO(blakely): Consider using the analog watchdog to set battery/voltage sense range
- Consideration: ADC sampling time _independent from_ AHB bus clock freq
  - Well, looks like it _can_ be? I think it can either be AHB or the PLLP clock
  - Former allows for division rates of 1/2/4, latter is 1/2/4/6/8/10/12/16/32/64/128/256
  - I think the following is only relevant with injected channels:
    
- So working on bringing up ADC4 peripheral
  - GPIO pin set to `analog()`
    - Don't think there's anything else we need to do for the ADC pins
  - Using AHB bus, so not turning on PLLP in RCC
  - But we _do_ need to turn on ADC[1-4] _peripherals_; done
  - I don't think we need

_Got a bit sidetracked by rust-analyzer telling me it can't find `test` package. [Found](https://github.com/rust-analyzer/rust-analyzer/issues/3801) that by default it tries to analyze `--all-targets` and needed to specify only the `thumbv7em-none-eabihf` target. Anyway..._

_Oh yeah, TODO(blakely): look into adding a channel for V_REFINT to make sure the V_REF is where it's supposed to be_

  - Looks like there's an internal calibration, and it has to be done _after_ waking from deep-powerdown
    - If you set `DEEPPWD`, then the ADC voltage regulator `ADVREGEN` is cleared
    - If you only clear `ADVREGEN` but stay out of `DEEPPWD`, calibration is kept
    - Calibration persists between ADC enable/disable (`ADEN`)
      - But for long periods new clibration is suggested
    - Must wait until calibration is done
    - Can technically write it directly to `ADC_CALFACT` register
    - Can only be written if ADC enabled but NOT converting (`ADEN=1` and `ADSTART=0` and `JADSTART=0`)

_Another distraction! It seems like `cargo fmt` doesn't like `edition = "2021"`, erroring out with `invalid value for '--edition' `. Guess I'll go back to 2018 for now; worst case we wait <= 6 weeks for it to roll out to the public._

  - [unindent to get around a [weird markdown bug](images/2021-07-29-00-01-32.png)...?]
    - Oof. Looks like the `TADCVREG_STUP` [startup time for the g4 is 20us](images/2021-07-29-00-03-27.png)... looks like I'm going to have to implement a blocking wait. Maybe based on systick?
    - Looks like SysTick is handled as an "exception" instead of an "interrupt"... wonder if that's nomenclature form Arm, or just convention
    - I'm going to need to implement a blocking systick handler for things that require actual timing (without sacrificing a timer)
    - Will have to do that next time...

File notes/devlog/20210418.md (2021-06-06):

Spinning up Tim1 for 3-phase with enforced deadtime.
- Looks like it's up and running (`CNT` is spinning) but I'm not seeing anything on the output pins
  - Pins are PA[8910]
  - AF mode: check
  - Output type PushPull: check
  - Speed very high: check
  - Floating: check
  - Alternate function 6: check
- Probably a setting in Tim1 that's not set then...
  - CC channels enabled: check
  - PWM mode: check
- Oh, wait, it's probably the 3-phase deadtime PWM setting. Ayup, that's it: disabling the 3-phase
  AND on channel 5 gets PWMs like we'd expect
  
  - Turns out the PWM mode wasn't set for ch5; it was defaulting to "frozen" status
- And all systems go on hardware-enforced deadtime! The PWM traces are now logical ANDed with TIM1
  ch5. Top trace is a typical ~24% trace. It's AND'd with ch5 (cyan). In this case, doesn't really
  matter much; the deadtime is enforced during the low phase of the PWM.
  
- Now if we set the timer channel to 100% duty cycle, it's AND'd with the tim5 channel at 98%, which
  results in the output PWM being "clamped" to 98% duty cycle
  

Next: get the tim1 update trigger to cause an interrupt
- So it works... but seeing some interesting latency'
  
  - That's the PWM dead zone centered around INH_A's off PWM start
  - The start of the timer loop itself should be right smack in the middle of that yellow trace;
    it's hardware generated aka no software overhead
  - The weird part is that the cyan trace is bit-banging a GPIOB pin
  - From the roughly center of the hardware PWM trace - where I expect the Update interrupt is
    triggered- there's about ~165ns of latency between the interrupt triggering and the pin toggling
  - Assuming the pin can be toggled "immediately", that's 12 cycles to enter the ISR + 3 to load and
    set the `BSRR` register
  - With that assumption, that's ~88ns. Though that _does_ include a `device::Peripheral::steal()`
    and a "zero overhead" write to the register
  - I wonder if I can just slam a bit into the `BSRR` register and see what the latency is
- Whelp, best case scenario: about 125ns?
  
  - That's writing the register directly; unsafe code, no Tust, no nothin'
  - 300ns over what the disassembly shows is... 13 instructions? Maybe 15?
    
  - Only thing I can think of is that it's flash and not CCM...?
  - Still not a terrible latency overall. Will have to experiment with CCM interrupt handlers.
  - The main goal of this whole process was to try to get a sense of the latency between when an
    update is fired and when I can first see something on the

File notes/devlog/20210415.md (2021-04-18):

- Today's goal: finish DRV8323RS registers and get configuration set up for ADV control timers
  - Maybe that was a biiiit to optimistic. Turns out the DRV8323 has a _lot_ of enum valiues for calibration...
    - Maybe someday I can convince TI to release Rust libraries...
      - [In my dreams...]
  - So looks like we can read registers fine, but writing doesn't seem to be enabling the SPI or actually writing anything
  - Okay, now that the SPI is being enabled/disabled in the `update()` call... :musical_note: which one of these, is not like the others? :musical_note:

    
    - That's a 32 bit write... wat?
    - I'm guessing I'm either double-writing the DR register, or not clearing out the DR on read properly. Gotta check the SPI peripheral's FIFO
    - ...Also seeing a strange "You may have requested too many hardware breakpoints/watchpoints"?
      - Maybe my OpenOCD config is requesting a bunch or something? I only have three...
      - AFAICT it adds breakpoints to muliple places in the Rust code if there are closures, instead of the first occurrence. Might want to file a bug on that
  - Ah, there we go:

    
    - Wasn't waiting for the `bsy()` signal during writing
    - I wonder if there isn't a Rust-y way to deal with that
      - Maybe a TypeState pattern, like "Wrote `dr`, unable to do anything else until we block and `bsy` is clear"?
      - Wait, maybe SPI should have a `blocking_read()` typestate change? It's not necessarily relevant to the DRV8323 chip

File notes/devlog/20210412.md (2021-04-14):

Today's goal: Get MA702 abstraction up and running.

- Going back and forth on whether the SPI peripheral should be configured within the MA702 or by
  the driver itself
- Man, Rust _really_ makes you think about ownership and lifetimes. That's A Good Thing
  - I was thinking I could just get a reference to the `DMA1` peripheral and keep it in the MA702 so that I could stop it after starting it
  - But Rust began yelling at me that it outlived its scope... and it was right!
  - In the Controller, I'm using the Typestate pattern to ensure that only certain methods can be called on it at any given time. When going from `Controller<Init>` to `Controller<Ready>`, I was doing something like this:
    ```rust
    pub fn configure_peripherals(self) -> Controller<Ready> {
        let ma702 = ma702::new(self.mode_state.spi1)
            .configure_spi()
            .begin_stream(&self.mode_state.dma1, &self.mode_state.dmamux);
        // ...snip...
        let new_self = Controller {
            mode_state: Ready { ma702 },
        };
        new_self
    }
    ```
  - If you look carefully, you'll notice that the `ma702` gets a reference to `self.mode_state.dma1`. That reference holds all the way until the return statement, but _then it's dropped!_
  - Why? Because of the combination of three things:
    1. We're creating a new Controller object that takes ownership of anything it's given
    2. The new controller only references the `ma702` object, which is kept alive
    3. The original `Controller` is `Drop`'d, along with everything inside that we didn't transfer.
  - During #2, Rust keeps track of the reference the `ma702` has and keeps it alive during the transfer, but _the `dma1` object within `self.mode_state` gets dropped by #3!_ How can it maintain a reference to something that's dropped?!
  - There are a few potential solutions:
    - Remove the reference kept in MA702
      - Easy way out; took this route for now :sweat_smile:
    - Transfer ownership of `DMA1` to the MA702
      - Okay for now, but would prevent anyone else from doing anything with that DMA
    - Transfer the ownership of the DMA into the new Controller to keep it - and anything that references it - alive
      - A bit more appropriate
    - Split the `DMA1` controller into individual `DmaStream`s that own their respective registers.
      - Best approach in the long run, but haven't had the need for more than one or two DMA streams, so that's an optimization for down the road.

- Onto DRV8323
  - Enable pin works
  - Clock seems to work, but nothing else...? Gotta double-check those GPIO pins...
  - MOSI works now... accidentally `&`'d together bits instead of `|` /shamecube.gif
  - Everything works, but apparently it takes a while until the SPI is ready. Datasheet says 1ms:
    
  - Implemented a crude blocking loop.

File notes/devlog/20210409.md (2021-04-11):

- Now that FDCAN is complete, time to get SPI communication up and running
  - Got it working surprisingly fast!
    
  - The CS line is... weird when controlled by hardware. Here it is after manually turning off the
    peripheral after the transfer is complete:
    
  - Cool, as expected, it allows the pullup on the CS line to bring it back to 3.3v. All good!
    - Oh, wait, no, that's the initial drop when the GPIO pin is configured in AF mode :sweat_smile:

    
  - There we go, much better. That's manually turning off the peripheral after the transfer is complete (busy-wait spinning on `SPI1.SR[BSY]`)
  - What happens if we complete the transfer, but _don't_ disable the peripheral?
    
    - Erm, okay, I don't really think we need to keep the external chip selected, but whatever floats your boat ST.
    - Let's try it with `SPI1.CR1[NSSP]` set to `1`, which according to the reference manual _"is used in master mode only. it allows the SPI to generate an NSS pulse between two consecutive data when doing continuous transfers. In the case of a single data transfer, it forces the NSS pin high level after the transfer."_
    
    - Wait, _WHAT?!_ This _never ever ever ever_ worked with any of the libs provided by ST, either the HAL nor the LL. Apparently the hardware-driven CS ... does work?
    - Woot, I guess? /shamecube.gif One less thing to worry about when mucking with the peripherals

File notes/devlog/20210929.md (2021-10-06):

## TODO(blakely): Bring Our Listeners Up To Speed

[A lot has happened](https://www.youtube.com/watch?v=pH46vk3P4NE). Have yet to copy over notes from Discord, but will get around to it Soon:tm:.

## Communication

Trying to flesh out some details/designs around communication here
- The API surrounding the communications API (FDCAN) is kinda... terrible at the moment
  - Was following the "get it working, then make it better" philosophy. Now it works, it's just going to get out of hand real quick if I don't fix it now

Modes of communication:
- Mode select
  - Effectively changing the finite state machine of the controller e.g. start commutation, do calibration, etc
  - Changing different

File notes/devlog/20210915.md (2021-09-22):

# Designing the current control loop

**Man** do I appreciate how thorough Ben was in his thesis. It's been incredibly helpful in my
learning of ... basically everything I'm trying to learn? :sweat_smile:
- That said... definitely found a few errors in it by now
- Turns out the Bode plots he showed in his thesis didn't actually match what his code in Appendix C suggested
- (also, `l` in his Appendix C doesn't exist in his code, but that's just being nit-picky :upside_down: )

But I did finally manage to reproduce the paramters he used to generate his Bode plots in appendix C.2



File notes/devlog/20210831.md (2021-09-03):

# Capturing callbacks in Rust with Trait Objects

Been searching for a proper replacement for `IRef` since `core::mem::transmute` is all sorts of UB...

@matt1992 - 512 bad getaway error from the Rust discord suggested [this
approach](https://play.rust-lang.org/?version=stable&mode=debug&edition=2018&gist=da89459eac77684a6fd042a9fc586897)
to trait objects:

```rust
use core::cell::Cell;
use core::marker::PhantomData;

fn main(){
    {
        let mut data = 0;
        let closure = &mut inder_hrtb(|add, _, _, _|{
            data+=add;
            println!("data:{}", data);
        });
        let mut closure = Closure::new(closure);
        closure.call(1, &mut TargetBuffer, &mut RasterCtx, priority::I0);
        closure.call(2, &mut TargetBuffer, &mut RasterCtx, priority::I0);
        closure.call(3, &mut TargetBuffer, &mut RasterCtx, priority::I0);
        closure.call(4, &mut TargetBuffer, &mut RasterCtx, priority::I0);
    }
}

struct Closure<'a>{
    data: *mut (),
    call: unsafe fn(*mut (), usize, &mut TargetBuffer, &mut RasterCtx, priority::I0),
    _marker : PhantomData<(
        // lifetime is invariant over `'a`
        fn(&'a ()) -> &'a (),

        // and this type is Send + !Sync
        Cell<()>,
    )>
}

fn inder_hrtb<F>(x: F) -> F
where
    F: FnMut(usize, &mut TargetBuffer, &mut RasterCtx, priority::I0),
{
    x
}

impl<'env> Closure<'env> {
    pub fn new<F>(func: &'env mut F) -> Self
    where
        F: FnMut(usize, &mut TargetBuffer, &mut RasterCtx, priority::I0),
        F: Send + 'env,
    {
        Self {
            data: func as *mut F as *mut (),
            call: call_closure::<F>,
            _marker: PhantomData,
        }
    }

    pub fn call(
        &mut self,
        arg0: usize,
        arg1: &mut TargetBuffer,
        arg2: &mut RasterCtx,
        arg3: priority::I0,
    ) {
        (self.call)(self.data, arg0, arg1, arg2, arg3)
    }
}

unsafe fn call_closure<F>(
    ptr: *mut (),
    arg0: usize,
    arg1: &mut TargetBuffer,
    arg2: &mut RasterCtx,
    arg3: priority::I0,
) where
    F: FnMut(usize, &mut TargetBuffer, &mut RasterCtx, priority::I0),
    F: Send,
{
    (*(ptr as *mut F))(arg0, arg1, arg2, arg3)
}

struct TargetBuffer;
struct RasterCtx;
mod priority {
    pub struct I0;
}
```

- With a [potential update](https://play.rust-lang.org/?version=stable&mode=debug&edition=2018&gist=183630f9d7e18ed5ab6a391b99ec4caf) of

```rust
fn with_closure<'env, F>(closure: &'env mut F)
where
    F: FnMut(usize, &mut TargetBuffer, &mut RasterCtx, priority::I0),
    F: Send + 'env,
{
    let mut closure = Closure::new(closure);
    closure.call(1, &mut TargetBuffer, &mut RasterCtx, priority::I0);
    closure.call(2, &mut TargetBuffer, &mut RasterCtx, priority::I0);
    closure.call(3, &mut TargetBuffer, &mut RasterCtx, priority::I0);
    closure.call(4, &mut TargetBuffer, &mut RasterCtx, priority::I0);
}

fn main(){
    let mut data = 0;
    with_closure(&mut |add, _, _, _|{
        data+=add;
        println!("data:{}", data);
    });
}
```

- Noting that _"The only erasure happening there (as well as with the previous code) is inside
Closure::new"_

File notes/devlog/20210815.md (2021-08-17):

# Deriving discrete-time control from the systems level

Okay, so I've learned a bit about laplacians, systems modeling, and transfer functions. Let's see if I can model this from first principles (with a _lot_ of help from [Ben's thesis](https://dspace.mit.edu/handle/1721.1/118671))

Table of common laplacians:

$$
\begin{array}{c:c}
 f(t) & f(s) \\ \hline
\delta(t) & 1 \\
x(t) & x(s) \\
\dot{x}(t) & sx(s) - x(0)\\
\ddot{x}(t) & s^2x(s) - sx(0) - \dot{x}(0)
\end {array}
$$

## System we're going to model

Since the mechanical responses are a few orders of magnitude slower than the electrical, we'll ignore the mechanical dynamics and only concentrate on the simplified stator loop:



- Starting from $v=iR$ and $v=L\frac{di}{dt}$, we can get the continuous voltage for this system as $v(t)=iR+L\frac{di}{dt}$
- If we want the continuous time frequency response - aka the response to an impulse at $\delta(t)$ - we need to move to laplacian space
  - The output is current $i(s)$ with control effort $v(s)$, so transfer function is $i(s)=H(s)v(s)$, where $H(s)$ is the _transfer function_
    - By algebra, $H(s)=\frac{i(s)}{v(s)}=\mathcal{L}\begin{Bmatrix}\frac{i(t)}{v(t)}\end{Bmatrix}$
  - $v(s)=\mathcal{L}\begin{Bmatrix}v(t)\end{Bmatrix}=\mathcal{L}\begin{Bmatrix}i(t)R+L\frac{di}{dt}\end{Bmatrix}$
  - Given table above, plugging in gives us $v(s) = i(s)R + Lsi(s) - i(0)$
  - Rearranging, assuming $i(0)=0$: $\frac{v(s)}{i(s)}=R + Ls$, and inverting for $H(s)$ gives $H(s)=\frac{i(s)}{v(s)}=\frac{1}{Ls + R}$
  - Note that it has a single pole at $-\frac{R}{L}$
- Now calculate the steady state response by setting $s=j\omega$ i.e. $H(j\omega)$
  - $H(j\omega)=\frac{1}{Lj\omega+R}$
  - Separate imaginary numbers in denominator by multiplying by the complex conjugate $\frac{R-Lj\omega}{R-Lj\omega}$
  - $H(j\omega)=\frac{1}{Lj\omega+R}\cdot\frac{R-Lj\omega}{R-Lj\omega}=\frac{R-Lj\omega}{R^2+L^2\omega^2}=\frac{R}{R^2+L^2\omega^2}-\frac{Lj\omega}{R^2+L^2\omega^2}$

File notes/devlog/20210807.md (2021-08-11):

# Reworking FDCAN

I'm really struggling to figure out the right API for the FDCAN. I tried something like this:

```rust
// Serialized/wire data
pub struct ReceivedMessage {
    pub id: u32,
    pub data: [u32; 16],
}

pub trait ExtendedFdcanFrame {
    // Unique ID for the frame
    fn id(&self) -> u32;

    // Unpack the message from a buffer.
    fn unpack(buffer: &[u32; 16]) -> Self;

    // Pack the message into a buffer of up to 64 bytes, returning the number of bytes that were
    // packed.
    fn pack(&self, buffer: &mut [u32; 16]) -> u8;
}

pub trait FdcanMessageTranslator {
    // Unique ID for the frame
    fn id(&self) -> u32;

    // Unpack the message from a buffer.
    fn unpack(message: &ReceivedMessage) -> Option<Self>
    where
        Self: Sized;

    // Pack the message into a buffer of up to 64 bytes, returning the number of bytes that were
    // packed.
    fn pack(&self, buffer: &mut [u32; 16]) -> u8;
}

pub struct Debug {
    pub foo: u32,
    pub bar: f32,
    pub baz: u8,
    pub toot: [u8; 3],
}

impl ExtendedFdcanFrame for Debug {
    fn id(&self) -> u32 {
        0xA
    }

    fn unpack(buffer: &[u32; 16]) -> Debug {
        Debug {
            foo: buffer[0],
            bar: f32::from_bits(buffer[0]),
            baz: (buffer[2] >> 24) as u8,
            toot: [
                ((buffer[2] & (0xFF << 16)) >> 16) as u8,
                ((buffer[2] & (0xFF << 8)) >> 8) as u8,
                (buffer[2] & 0xFF) as u8,
            ],
        }
    }

    fn pack(&self, buffer: &mut [u32; 16]) -> u8 {
        buffer[0] = self.foo;
        buffer[1] = self.bar.to_bits();
        buffer[2] = (self.baz as u32) << 24
            | (self.toot[2] as u32) << 16
            | (self.toot[1] as u32) << 8
            | (self.toot[0] as u32);
        24
    }
}

pub struct Debug2 {
    pub first: u32,
    pub second: i32,
}

impl ExtendedFdcanFrame for Debug2 {
    fn id(&self) -> u32 {
        0xB
    }

    fn unpack(buffer: &[u32; 16]) -> Debug2 {
        Debug2 {
            first: buffer[0] as u32,
            second: buffer[1] as i32,
        }
    }

    fn pack(&self, buffer: &mut [u32; 16]) -> u8 {
        buffer[0] = self.first as u32;
        buffer[1] = self.second as u32;
        8
    }
}

enum Messages {
    Debug(Debug),
    Debug2(Debug2),
}

impl FdcanMessageTranslator for Messages {
    fn id(&self) -> u32 {
        match self {
            Self::Debug(x) => x.id(),
            Self::Debug2(x) => x.id(),
        }
    }

    fn unpack(message: &ReceivedMessage) -> Option<Self> {
        match message.id {
            0xA => Some(Messages::Debug(Debug::unpack(&message.data))),
            0xB => Some(Messages::Debug2(Debug2::unpack(&message.data))),
            _ => None,
        }
    }

    fn pack(&self, buffer: &mut [u32; 16]) -> u8 {
        match self {
            Self::Debug(x) => x.pack(buffer),
            Self::Debug2(x) => x.pack(buffer),
        }
    }
}
```

But the double-indirection through `Messages` felt kinda wrong. Though it _did_ allow me to `match`
on it...

- Moving towards something I think it probably pretty sane for now: a modification of the above but
  getting rid of the `FdcanMessageTranslator` trait; the peripheral doesn't need to know about it
- Hm, not seeing the right values when unpacking...?
  - Checking the RXFIFO0 in FDCAN SRAM I see the right values that I sent via [fdcanusb](https://github.com/mjbots/fdcanusb)
  - So suggests it's downstream oddness somewhere
  - WAITWAITWAITWAIT... Ugh. It works perfectly. I was using Python's `struct.pack`, but it was
    packing to _native_ sizes... aka 64 bit :facepalm:
- And it works. We'll see if this is the right API. Anyway... now to commutation

**Problem:** need to get the control parameters from the main control loop (where the instructions come
in over FDCAN) and into the control loop.

- Can't use a read/write lock, since that'd deadlock in the ISR
- Can't disable interrupts (e.g. via critical sections) since we can't change the control loop frequency
- First thought: transactional (exclusive buffer?) lock
  - Requires two buffers: the main thread writes to one and the ISR reads from the other
  - Who reads from what is controlled by the main thread, since it's sending data to the ISR and
    the ISR can preempt
  - I think this can be accomplished via an atomic compare/exchange

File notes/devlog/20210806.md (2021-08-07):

# Reworking to be more Rusty

I've spent quite a bit twiddling registers. While that's needed to get the control loop up and running, that's not exactly why Rust is awesome. I'm going to work on getting the FDCAN comms up to date so I can actually send signals to the board instead of having to recompile and reflash.

- Attempting to move the FDCAN message handling into a callback in the controller
  - I think I may have one level too many of indirection in the FDCAN messages
  - We've got the struct `ReceivedMessage`, the trait `ExtendedFdcanFrame` and each implemented struct, e.g. `DebugMessage`
  - I wonder if I'm trying to do too much reflection here...?

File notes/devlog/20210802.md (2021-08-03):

## CORDIC

Putting the ADC2&3 work on hold for now; we'll need them before commutation, but we also need to calculate sines and cosines. LUTs would work, but since we've got the hardware why not use it?

One complication: the [CORDIC](https://en.wikipedia.org/wiki/CORDIC) coprocessor on the stm32g4 uses [fixed-point math](https://en.wikipedia.org/wiki/Fixed-point_arithmetic); in particular the [Q1.31 format](https://en.wikipedia.org/wiki/Q_(number_format)). I'm familiar with how they work - it's kinda nice that they saturate on over/underflow - but I'd rather not implement my own conversions. Good thing there's [a crate for that](https://crates.io/crates/fixed)!

- Looks like precision is a function of the number of iterations (makes sense)
  
  - Seems like 18 will get me to 1e-5, so we'll start there.
  - Oops, nevermind, looks like it's multiples of 4.
  - Woah: _"The CORDIC can perform four iterations per clock cycle."_ That's _way_ faster than I thought it was going to be
  - Screw it, let's go to 20. That gets us 2^-18 precision (3.8E-6)
- Well that was easy
  - Can calculate sine and cosine in 1x mem load, 5 clock cycles, and 2x mem reads
    - (Cheating a little bit, that doesn't include the conversion to/from Q1.31 :zany_face:)
  - And note that the 5 clock cycles can be asynchronous
  - That's with a precision of at least 2^-18
  - Given FLASH wait states that may actually be faster than a lookup table...

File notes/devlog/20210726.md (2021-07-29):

## Back at it!

- Going to update to `rust2021` and see how this goes...
  - Looks like the tool for `cargo fix` doesn't like my `third_party` setup... I think it has to do something with the `[[bin]]` and `!#[no_std]`
  - And done!
- Okay, getting a quick jupyter notebook up and runing to try and simulate a dumb motor for FOC
  - Yeesh, took way longer than expected to get Jupyter + VSCode integrated
    - Looks like a recent update added native support for Notebooks, but there's _also_ the extension? And they appear to fight each other for configuration...?
  - Oof, finally found the right incantation to change tabs to 2:
    ```json
    "notebook.editorOptionsCustomizations": {
        "codemirror_options": {
            "indentUnit": 2
        }
    }
    ```
- Okay, testing out Park/Clark transforms
  - Forward Clark:

    
  - Forward Park:

    
  - Inverse Park:

    
  - Inverse Clark:

    
  - Looking good so far (see [notebook](../../notebooks/foc_transforms.ipynb)):
    - `PerfectMotor` currents:

      

    - Clark transform:

      

    - Park transform:

      
  - One thing that's a bit counter-intuitive to me so far is the $\theta_\lambda$ in this has to be _negative_:

    
    - I guess that _kinda_ makes sense... it's the theta of $A$ _relative to_ the $d$ axis; put
      another way, what transform do you apply to get it back into $A$ space?

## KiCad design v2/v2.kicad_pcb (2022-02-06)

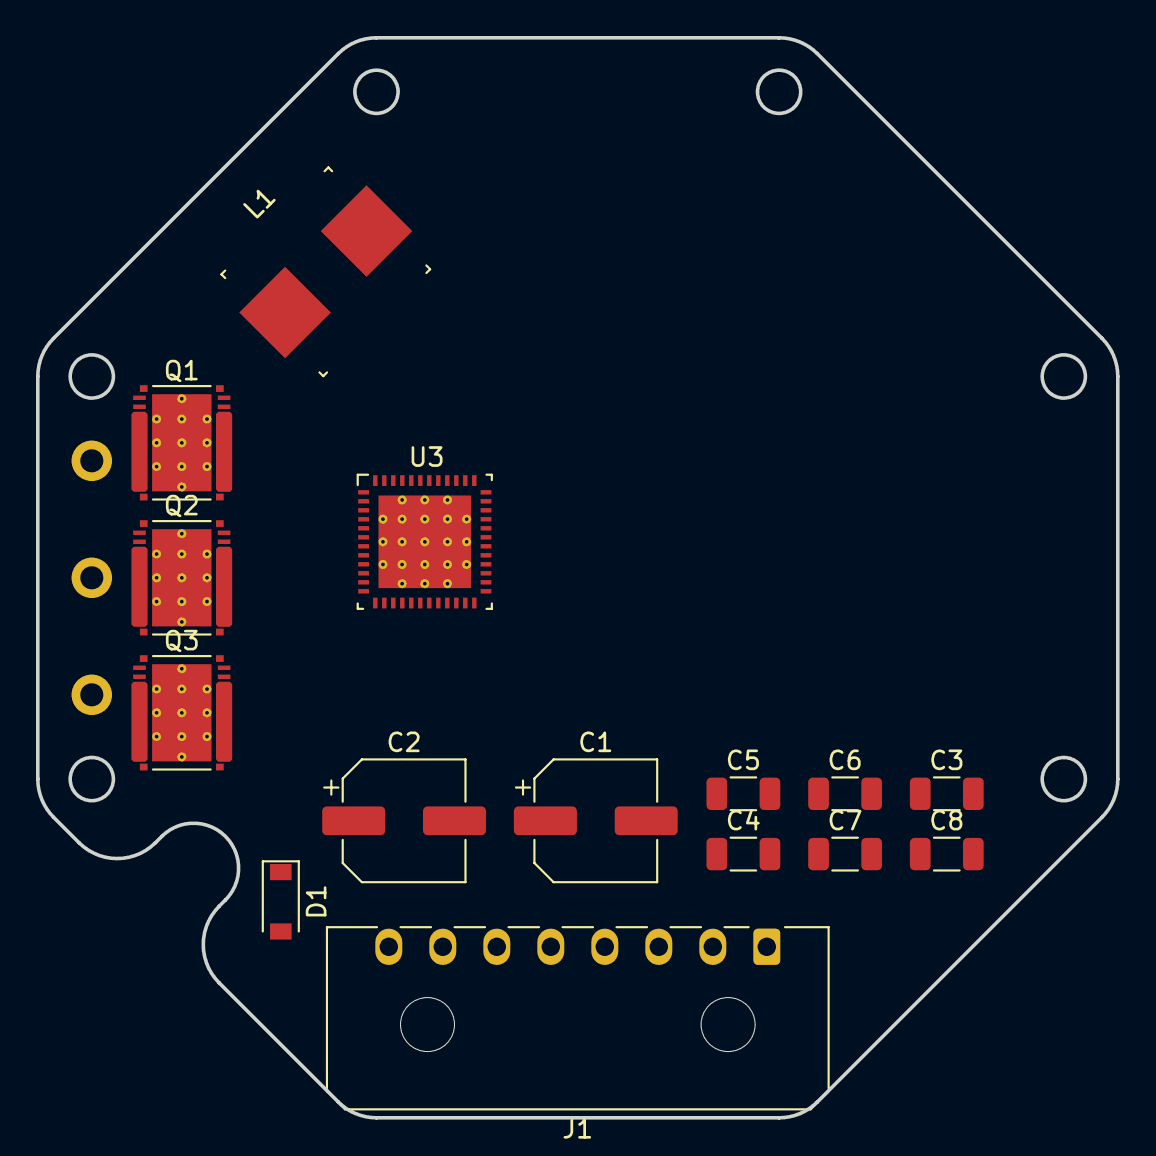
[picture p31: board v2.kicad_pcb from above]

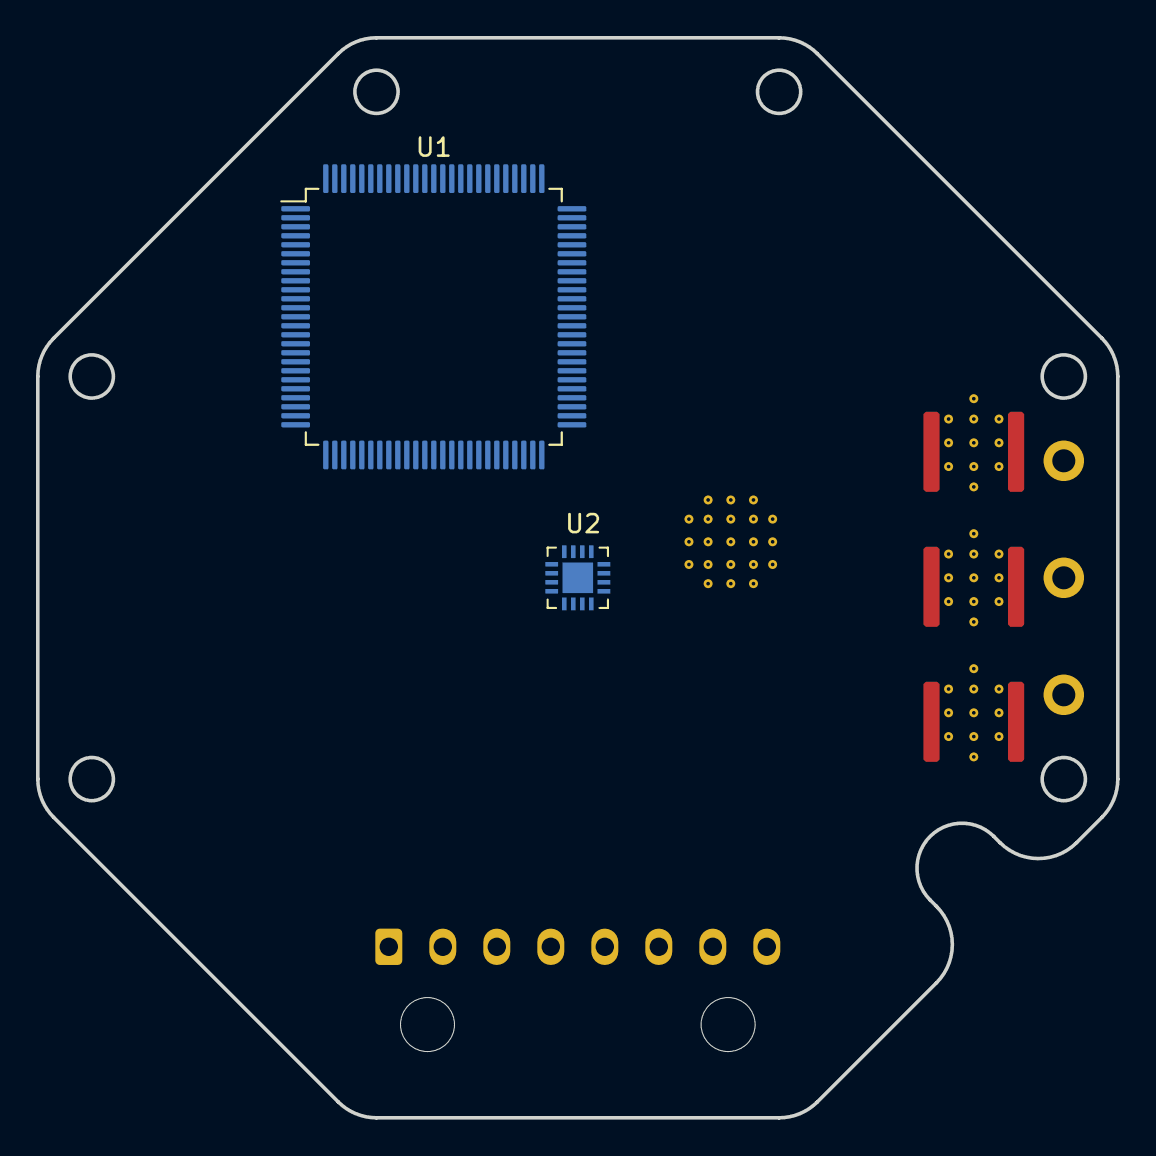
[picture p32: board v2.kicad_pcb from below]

Board: 4 copper layers, 60.0 x 60.0 mm, 20 parts (2 on the bottom side), 5 nets, no tracks yet.

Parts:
C1, C2: 22uF; CP_Elec_6.3x5.4
C3, C4, C5, C6, C7, C8: 10 uF; C_1206_3216Metric
D1: D_TVS; D_SOD-123
J1: Conn_01x08; Molex_Micro-Fit_3.0_43650-0800_1x08_P3.00mm_Horizontal
J2, J3, J4: PTH; PTH_1.28mm_ID_2.25mm_OD
L1: L; PCC-M0754M
Q1, Q2, Q3: CSD88599Q5DC; DMM0022A
U1: STM32H725VGT6; LQFP-100_14x14mm_P0.5mm
U2: MA702GQ-Z
U3: DRV8323RS; DRV8323RHRGZR

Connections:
unnamed: J2.1 (PTH), Q1.3 (VSW), Q1.4 (VSW), Q1.5 (VSW), Q1.6 (VSW), Q1.7 (VSW), Q1.8 (VSW), Q1.9 (VSW), Q1.10 (VSW), Q1.11 (VSW)
unnamed: J3.1 (PTH), Q2.3 (VSW), Q2.4 (VSW), Q2.5 (VSW), Q2.6 (VSW), Q2.7 (VSW), Q2.8 (VSW), Q2.9 (VSW), Q2.10 (VSW), Q2.11 (VSW)
unnamed: J4.1 (PTH), Q3.3 (VSW), Q3.4 (VSW), Q3.5 (VSW), Q3.6 (VSW), Q3.7 (VSW), Q3.8 (VSW), Q3.9 (VSW), Q3.10 (VSW), Q3.11 (VSW)
unnamed: U3.2 (PGND), U3.49 (PGND)
PGND: Q1.12 (PGND), Q1.13 (PGND), Q1.14 (PGND), Q1.15 (PGND), Q1.16 (PGND), Q1.17 (PGND), Q1.18 (PGND), Q1.19 (PGND), Q1.20 (PGND), Q2.12 (PGND), Q2.13 (PGND), Q2.14 (PGND), Q2.15 (PGND), Q2.16 (PGND), Q2.17 (PGND), Q2.18 (PGND), Q2.19 (PGND), Q2.20 (PGND), Q3.12 (PGND), Q3.13 (PGND), Q3.14 (PGND), Q3.15 (PGND), Q3.16 (PGND), Q3.17 (PGND), Q3.18 (PGND), Q3.19 (PGND), Q3.20 (PGND)

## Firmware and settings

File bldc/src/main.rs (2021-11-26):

#![cfg_attr(not(test), no_std)]
#![no_main]

use bldc::comms::handlers::disable_control_loop::DisableControlLoop;
use bldc::comms::handlers::pos_vel_control::EnterPosVelControl;
use bldc::comms::handlers::set_pos_vel::SetPosVel;
use bldc::comms::handlers::torque_control::EnterTorqueControl;
use bldc::driver;

#[cfg(feature = "panic-halt")]
use panic_halt as _;
#[cfg(feature = "panic-itm")]
use panic_itm as _; // you can put a breakpoint on `rust_begin_unwind` to catch panics

// TODO(blakely): Comment on all the stuff that happens before we actually get here...
#[cortex_m_rt::entry]
fn main() -> ! {
    // Acquire the driver.
    let mut driver = driver::take_hardware().configure_peripherals().calibrate();
    // driver.on_message(|message: FdcanMessage| match Message::parse(message) {
    //     Message::CalibrateEZero(_) => {
    //         fdcan::send_message(&EZeroMsg {
    //             angle: 123.,
    //             angle_raw: 456,
    //             e_angle: 789.,
    //             e_raw: 1337.,
    //         });
    //     }
    //     Message::TorqueControl(cmd) => {
    //         Commutator::set(TorqueControl::new(cmd.duration, cmd.currents).into())
    //     }
    //     Message::PosVelControl => Commutator::set(PosVelControl::new().into()),
    //     Message::PosVelCommand(cmd) => {
    //         PosVelControl::command(cmd);
    //     }
    //     Message::BeginStateStream(cmd) => {
    //         let frequency = cmd.frequency.max(1.);
    //         timer::periodic_callback(frequency, frequency / 10_000., || {
    //             if let Some(state) = SENSOR_STATE.read() {
    //                 fdcan::send_message(&state);
    //             };
    //         });
    //     }
    //     Message::EndStateStream => {
    //         timer::stop_periodic_callback();
    //     }
    //     _ => (),
    // });

    driver.add_message_handler(EnterTorqueControl::new());
    driver.add_message_handler(EnterPosVelControl::new());
    driver.add_message_handler(SetPosVel::new());
    driver.add_message_handler(DisableControlLoop::new());

    driver.listen();
}

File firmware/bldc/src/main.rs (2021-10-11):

#![cfg_attr(not(test), no_std)]
#![no_main]

use bldc::{
    comms::fdcan::{self, IncomingFdcanFrame, OutgoingFdcanFrame},
    commutation::{
        calibrate_e_zero::{CalibrateEZeroCmd, EZeroMsg},
        pos_vel_control::{PosVelCommand, PosVelControl, PosVelMode},
        torque_control::{TorqueControl, TorqueControlCmd},
        Commutator, SensorState, SENSOR_STATE,
    },
    driver, timer,
};
use messages::Message;

#[cfg(feature = "panic-halt")]
use panic_halt as _;
#[cfg(feature = "panic-itm")]
use panic_itm as _; // you can put a breakpoint on `rust_begin_unwind` to catch panics

struct StartStreamCmd {
    pub frequency: f32,
}
impl IncomingFdcanFrame for StartStreamCmd {
    fn unpack(msg: fdcan::FdcanMessage) -> Self {
        let buffer = msg.data;
        StartStreamCmd {
            frequency: f32::from_bits(buffer[0]),
        }
    }
}

struct StopStreamCmd {}
impl IncomingFdcanFrame for StopStreamCmd {
    fn unpack(_: fdcan::FdcanMessage) -> Self {
        StopStreamCmd {}
    }
}

// TODO(blakely): Comment on all the stuff that happens before we actually get here...
#[cortex_m_rt::entry]
fn main() -> ! {
    // Acquire the driver.
    let mut driver = driver::take_hardware().configure_peripherals().calibrate();

    driver.on(Message::CalibrateEZero, |_: CalibrateEZeroCmd| {
        fdcan::send_message(&EZeroMsg {
            angle: 123.,
            angle_raw: 456,
            e_angle: 789.,
            e_raw: 1337.,
        });
    });

    driver.on(Message::TorqueControl, |cmd: TorqueControlCmd| {
        Commutator::set(TorqueControl::new(cmd.duration, cmd.currents))
    });

    driver.on(Message::PosVelControl, |_: PosVelMode| {
        Commutator::set(PosVelControl::new())
    });

    driver.on(Message::PosVelCommand, |cmd: PosVelCommand| {
        PosVelControl::command(cmd);
    });

    driver.on(Message::BeginStateStream, |cmd: StartStreamCmd| {
        let frequency = cmd.frequency.max(1.);
        timer::periodic_callback(frequency, frequency / 10_000., || {
            if let Some(state) = SENSOR_STATE.read() {
                fdcan::send_message(&state);
            };
        });
    });

    driver.on(Message::EndStateStream, |_cmd: StopStreamCmd| {
        timer::stop_periodic_callback();
    });

    driver.listen();
}

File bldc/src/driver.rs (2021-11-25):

use crate::comms::fdcan::{self, Fdcan, Running};
use crate::comms::messages::FdcanID;
use crate::comms::MessageHandler;
use crate::control_loops::calibrate_adc::CalibrateADC;
use crate::control_loops::{ControlHardware, Controller};
use crate::cordic::Cordic;
use crate::encoder::Encoder;
use crate::pwm::PwmOutput;
use crate::timer::TimerConfig;
use crate::util::stm32::{
    clock_setup, clocks::G4_CLOCK_SETUP, disable_dead_battery_pd, donate_systick,
};
use crate::{current_sensing, timer};
use crate::{ic::drv8323rs, ic::ma702};
use cortex_m::peripheral as cm;
use drv8323rs::Drv8323rs;
use heapless::FnvIndexMap;
use stm32g4::stm32g474 as device;
use third_party::m4vga_rs::util::armv7m::{disable_irq, enable_irq};

const V_BUS_GAIN: f32 = 16.0; // 24v with a 150k/10k voltage divider.

pub struct Driver<S> {
    pub mode_state: S,
    message_handlers: FnvIndexMap<u32, MessageHandler, 16>,
    controller: Controller,
}

pub struct DriverHardware {
    pub drv: Drv8323rs<drv8323rs::Ready>,
    pub gpioa: device::GPIOA,
    pub fdcan: Fdcan<Running>,
}

pub struct Init {
    pub fdcan: device::FDCAN1,
    pub gpioa: device::GPIOA,
    pub gpiob: device::GPIOB,
    pub gpioc: device::GPIOC,
    pub spi1: device::SPI1,
    pub spi3: device::SPI3,
    pub tim1: device::TIM1,
    pub tim2: device::TIM2,
    pub tim3: device::TIM3,
    pub dma1: device::DMA1,
    pub dmamux: device::DMAMUX,
    pub adc12: device::ADC12_COMMON,
    pub adc1: device::ADC1,
    pub adc2: device::ADC2,
    pub adc345: device::ADC345_COMMON,
    pub adc3: device::ADC3,
    pub adc4: device::ADC4,
    pub adc5: device::ADC5,
    pub cordic: device::CORDIC,
}

pub struct Calibrating {
    pub hardware: DriverHardware,
}

pub struct Ready {
    pub hardware: DriverHardware,
}

pub fn take_hardware() -> Driver<Init> {
    let cp = cm::Peripherals::take().unwrap();
    let p = device::Peripherals::take().unwrap();

    // Donate the SYST peripheral to the blocking sleep handler so it's available anywhere.
    donate_systick(cp.SYST);

    init(
        cp.NVIC,
        p.RCC,
        p.FLASH,
        p.PWR,
        p.GPIOA,
        p.GPIOB,
        p.GPIOC,
        p.FDCAN1,
        p.SPI1,
        p.SPI3,
        p.TIM1,
        p.TIM2,
        p.TIM3,
        p.DMA1,
        p.DMAMUX,
        p.ADC12_COMMON,
        p.ADC1,
        p.ADC2,
        p.ADC345_COMMON,
        p.ADC3,
        p.ADC4,
        p.ADC5,
        p.CORDIC,
    )
}

fn init(
    mut nvic: cm::NVIC,
    rcc: device::RCC,
    flash: device::FLASH,
    pwr: device::PWR,
    gpioa: device::GPIOA,
    gpiob: device::GPIOB,
    gpioc: device::GPIOC,
    fdcan: device::FDCAN1,
    spi1: device::SPI1,
    spi3: device::SPI3,
    tim1: device::TIM1,
    tim2: device::TIM2,
    tim3: device::TIM3,
    dma1: device::DMA1,
    dmamux: device::DMAMUX,
    adc12: device::ADC12_COMMON,
    adc1: device::ADC1,
    adc2: device::ADC2,
    adc345: device::ADC345_COMMON,
    adc3: device::ADC3,
    adc4: device::ADC4,
    adc5: device::ADC5,
    cordic: device::CORDIC,
) -> Driver<Init> {
    disable_dead_battery_pd(&pwr);

    // Make sure we don't receive any interrupts before we're ready.
    disable_irq(device::Interrupt::ADC1_2);
    disable_irq(device::Interrupt::DMA1_CH2);
    disable_irq(device::Interrupt::FDCAN1_INTR0_IT);
    disable_irq(device::Interrupt::FDCAN1_INTR1_IT);

    // Set up the core, AHB, and peripheral buses.
    clock_setup(&pwr, &rcc, &flash, &G4_CLOCK_SETUP);

    // Enable Flash cache and prefetching for full speed.
    flash
        .acr
        .modify(|_, w| w.dcen().enabled().icen().enabled().prften().enabled());

    // FDCAN configuration
    // Turn on PLLQ so that we can use that for FDCAN
    // TODO(blakely): Is this necessary? Can't we just use the PCLK1? CubeMX seems to think so...
    rcc.pllcfgr
        .modify(|_, w| w.pllqen().set_bit().pllq().div2());

    // Enable various peripheral clocks
    rcc.ccipr.modify(|_, w| w.fdcansel().pllq());
    rcc.ahb1enr.modify(|_, w| {
        w.dma1en()
            .enabled()
            .dmamuxen()
            .enabled()
            .cordicen()
            .set_bit()
    });
    rcc.ahb2enr
        .modify(|_, w| w.adc12en().enabled().adc345en().enabled());
    rcc.apb1enr1
        .modify(|_, w| w.fdcanen().enabled().tim2en().enabled().tim3en().enabled());
    rcc.apb2enr
        .modify(|_, w| w.spi1en().enabled().tim1en().enabled());

    // Turn on GPIO clocks.
    rcc.ahb2enr.modify(|_, w| {
        w.gpioaen()
            .set_bit()
            .gpioben()
            .set_bit()
            .gpiocen()
            .set_bit()
    });

    // Turn on SPI1 (Encoder) clock.
    rcc.apb2enr.modify(|_, w| w.spi1en().set_bit());
    // Turn on SPI3 (DRV8323RS) clock.
    rcc.apb1enr1.modify(|_, w| w.spi3en().set_bit());

    // Configure interrupt priorities.
    // Safety: messing with interrupt priorities is inherently unsafe, but we disabled our device
    // interrupts above.
    unsafe {
        // Ensure that the control loop is at the absolute highest priority.
        nvic.set_priority(device::Interrupt::ADC1_2, 0x0);
        // Next is the DMA request reading the MA702 (if used).
        nvic.set_priority(device::Interrupt::DMA1_CH2, 0x10);
        // The periodic callback on TIM2 is low priority.
        nvic.set_priority(device::Interrupt::TIM2, 0xFF);
        // Finally the FDCAN.
        nvic.set_priority(device::Interrupt::FDCAN1_INTR0_IT, 0xFF);
        nvic.set_priority(device::Interrupt::FDCAN1_INTR1_IT, 0xFF);
    }

    Driver {
        mode_state: Init {
            fdcan,
            gpioa,
            gpiob,
            gpioc,
            spi1,
            spi3,
            tim1,
            tim2,
            tim3,
            dma1,
            dmamux,
            adc12,
            adc1,
            adc2,
            adc345,
            adc3,
            adc4,
            adc5,
            cordic,
        },
        message_handlers: FnvIndexMap::new(),
        controller: Controller::new(),
    }
}
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

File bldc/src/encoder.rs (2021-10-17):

use crate::ic::ma702::{Ma702, StreamingPolling};
use core::f32::consts::PI;
use third_party::ang::{AbsoluteDist, Angle};

const TWO_PI: f32 = PI * 2.;

struct PllObserverRadians {
    kp: f32,
    ki: f32,
    min_d_theta: Angle,
    angle: Option<Angle>,
    velocity: Angle,
    d_theta: Angle,
}

struct PllObserverState {
    angle: Angle,
    velocity: Angle,
}

impl PllObserverRadians {
    pub fn with_bandwidth(bandwidth: f32, min_d_theta: Angle) -> Self {
        // This is based on a critically-damped pos/vel observer where the poles are on top of each
        // other. The `A` matrix is effectively $\begin{vmatrix}-k_p & 1 \\ -k_i & 0 \end{vmatrix}$,
        // which after running through SymPy for the eigenvalues (`Matrix([[-x, 1], [-y,
        // 0]]).eigenvals()`) gives us $kp = -2 * bandwidth$ and $ki = \frac{k_p^2}{4}$
        // For more info, see [this thread on ODrive's
        // forum](https://discourse.odriverobotics.com/t/rotor-encoder-pll-and-velocity/224/4)
        let kp = 2.0 * bandwidth;
        let ki = 0.25 * (kp * kp);
        // TODO(blakely): Don't panic here; return a `Result`.
        if kp < 1. {
            panic!(
                "Observer bandwidth needs to be >= 0.5 due to discretization limitations. At {} \
             rads/s kp={}",
                bandwidth, kp
            );
        }
        PllObserverRadians::with_gains(kp, ki, min_d_theta)
    }

    // Allow instantiating with gains directly
    pub fn with_gains(kp: f32, ki: f32, min_d_theta: Angle) -> Self {
        // TODO(blakely): Don't panic here; return a `Result`.
        if kp < 1. {
            panic!("Due to discretization kp must be >= 1.0. Got {}", kp);
        }
        PllObserverRadians {
            kp,
            ki,
            angle: None,
            velocity: Angle::Radians(0.),
            min_d_theta,
            d_theta: Angle::Radians(0.),
        }
    }

    pub fn update(&mut self, dt: f32, new_reading: Angle) -> PllObserverState {
        let previous_angle = match self.angle {
            Some(x) => x,
            None => {
                self.angle = Some(new_reading);
                self.velocity = Angle::Radians(0.);
                return PllObserverState {
                    angle: new_reading,
                    velocity: self.velocity,
                };
            }
        };
        let previous_velocity = self.velocity;

        // Predict the current position.
        let angle = previous_angle + dt * previous_velocity;

        // Calculate change in theta.
        // let d_theta = match new_reading - angle {
        //     d_angle if d_angle.in_radians() > PI => Angle::Radians(d_angle.in_radians() - TWO_PI),
        //     d_angle if d_angle.in_radians() <= -PI => Angle::Radians(d_angle.in_radians() + TWO_PI),
        //     d_angle => d_angle,
        // };
        let d_theta = new_reading.abs_dist(angle);

        // Discrete phase detector. We need to discretize the continuous (float) prediction above,
        // so we need to figure out if the prediction is ahead or behind of where the actual
        // observed angle is. If our predicted angle is a bit behind and discretization hasn't
        // stepped up to the new value yet, but the encoder _has_, the following will be 1.0f.
        let error = match d_theta {
            x if x <= -self.min_d_theta => -1.,
            x if x >= self.min_d_theta => 1.,
            _ => 0.,
        };
        // Update the predicted angle based on the damping effect of kp, and update the velocity
        // measurement (stiffness?).
        let new_angle = (angle + Angle::Radians(dt * self.kp * error)).normalized();
        self.angle = Some(new_angle);
        self.velocity = previous_velocity + Angle::Radians(dt * self.ki * error);
        self.d_theta = d_theta;

        PllObserverState {
            angle: new_angle,
            velocity: self.velocity,
        }
    }
}

#[derive(Clone, Copy)]
pub struct EncoderState {
    pub raw_encoder: u16,
    pub angle: Angle,
    pub velocity: Angle,
    pub angle_multiturn: Angle,
    pub electrical_angle: Angle,
    pub electrical_velocity: Angle,
}

pub struct Encoder {
    ma702: Ma702<StreamingPolling>,
    pole_pairs: u8,
    encoder_observer: PllObserverRadians,
    state: Option<EncoderState>,
}

impl Encoder {
    pub fn new(
        ma702: Ma702<StreamingPolling>,
        pole_pairs: u8,
        velocity_observer_bandwidth: f32,
    ) -> Encoder {
        Encoder {
            ma702,
            pole_pairs,
            encoder_observer: PllObserverRadians::with_bandwidth(
                velocity_observer_bandwidth,
                Angle::Radians(TWO_PI / 4096.),
            ),
            state: None,
        }
    }

    pub fn update(&mut self, delta_t: f32) -> EncoderState {
        let angle_state = self.ma702.update(delta_t);
        let pll_state = self.encoder_observer.update(delta_t, angle_state.angle);
        let electrical_angle = (angle_state.angle * self.pole_pairs as f32).normalized();
        let electrical_velocity = pll_state.velocity * self.pole_pairs as f32;

        let mut new_state = EncoderState {
            raw_encoder: angle_state.raw_angle,
            angle: pll_state.angle,
            velocity: pll_state.velocity,
            angle_multiturn: pll_state.angle,
            electrical_angle,
            electrical_velocity,
        };

        if let Some(previous_state) = self.state {
            let d_theta = pll_state.angle.abs_dist(previous_state.angle);
            new_state.angle_multiturn = previous_state.angle_multiturn + d_theta;
        }
        self.state = Some(new_state);
        new_state
    }

    pub fn state(&self) -> &Option<EncoderState> {
        &self.state
    }
}

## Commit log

2021-03-28 Changed from generic 'app' name to 'bldc'
2021-03-29 Mostly notes on how stm32-rs does memory mapping. Also first stab at partial implementation of fdcan
2021-03-29 Broke out into proper locations
    [fdcan.rs, mod.rs]
2021-03-29 Standard filter complete
2021-03-31 Tx fifo + mask fixes
    [fdcan.rs]
2021-04-01 FDCAN work to get extended filters writing to memory
2021-04-03 Starting up FDCAN, but reference issues are messy still
    [driver.rs, fdcan.rs, stm32.rs]
2021-04-03 Solved compilation of fdcan
    [driver.rs, fdcan.rs, main.rs]
2021-04-03 Cleaning up FDCAN init chain. Rust is really neato.
2021-04-04 FDCAN frame transmitted
2021-04-06 FDCAN works for transmission (no error checking yet)
    [driver.rs, fdcan.rs, main.rs]
2021-04-10 Chain build and `cargo size` commands
2021-04-11 SPI up and running
2021-04-11 And presto, 1kHz SPI streaming!
2021-04-13 Broke out MA702 into its own implementation
    [driver.rs, ma702.rs, main.rs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]
2021-04-13 SPI working for DRV8323, needs refactor
2021-04-16 All registers for DRV8323 set up (may have bugs)
    [driver.rs, registers.rs]
2021-04-19 Hardware enforced deadtime and PWM on tim1
2021-06-06 Working out latency between interrupt firing and entering interrupt handler
2021-07-29 Clarify which SPI port
2021-07-29 Add picture of BLDC V1.0
2021-07-29 Add screenshot of ADC start-up time
2021-07-30 ADC4 calibration and startup
2021-07-30 Add notes on ADC and add app note
2021-07-30 VBat sensing working pretty well, about 1% error.
    [driver.rs]
2021-07-31 Begin support for current sense ADCs
2021-08-02 Got the current sense triggering via hardware!
2021-08-02 Add quick note about interrupt handlers
2021-08-03 Well, got the FETs to switch... and scream?
2021-08-04 PWMing the FETs!
2021-08-05 Phase A current sensing complete.
2021-08-07 Prior to reworking message structure
    [driver.rs, fdcan.rs, main.rs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]
2021-08-07 Not liking the current approach
2021-08-12 Passing hardware through to interrupt handler.
2021-08-12 Piped ma702 into interrupt
2021-08-15 Mainly notes over lapacians. Also modifying PWM on the fly
2021-08-17 More notes on calibration
2021-08-19 Fixed DRV startup in release mode
    [driver.rs, drv8323rs.rs]
2021-08-21 Beginning inductance measurement calibration
2021-08-22 First stab at current sensing
2021-08-22 Current sensing in sane units
2021-08-22 Vuvuzelas and power supplies *sigh*
2021-08-25 Added note on RF connectors for scope grounding
2021-08-27 Characterizing ADC noise
2021-08-27 New technique for stabilizing ADC current measurements
2021-09-07 FDCAN suddenly not working?
    [current_sensing.rs, driver.rs, interrupts.rs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]
2021-09-07 Current sensing triggered via FDCAN
2021-09-08 Pretty ugly, but FDCAN current sense working
2021-09-08 First stage of cleanup and simplification
2021-09-08 Move ADC handler into commutation
2021-09-09 Enabled current sense calibration during run
2021-09-10 Current sensing by RPC
2021-09-11 Bugfix: actually reset loop variable
    [inductance_measurement.rs]
2021-09-12 Increaes ADC calibration during startup to 2s
2021-09-14 Quick comment update in current_sensing
2021-09-15 Current measurement success
2021-09-17 Correct awful hardcoded PWM value in inductance measurment
    [measure_inductance.rs]
2021-09-18 Change resistance calib to be relative to Vbus
2021-09-19 Current-controlled loop. No more blowing up stators!
2021-09-23 Initial work on encoder: enabling DMA1 interrupt.
2021-09-23 Set correct priorities for the four interrupts
    [driver.rs]
2021-09-23 Bare encoder reading works
2021-09-24 Angle sensing up and running
    Moved tim3 into the MA702 and corrected the angle calculation.
    [driver.rs, ma702.rs]
2021-09-24 Swap out MA702 for higher level encoder.
    [driver.rs, encoder.rs, interrupt.rs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]
2021-09-24 Combine both locks in MA702 DMA interrupt.
2021-09-24 Fix odd comment break
    [main.rs]
2021-09-24 Enable G and R LED GPIOs.
2021-09-24 Correct DMA settings for MA702
    [ma702.rs]
2021-09-24 Pump MA702 polling to 100kHz
2021-09-24 Encoder and ma702 calculating electrical angle
    Includes rollover compensation and total angle calculation
2021-09-26 Use ang::Angle as the representation for the encoder
2021-09-26 Quick fix for Cordic linearization
    [cordic.rs]
2021-09-27 Getting at least a bit of commutation but something's broken
    [current_sensing.rs, driver.rs, encoder.rs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]
2021-09-27 Added ability to read encoder remotely via FDCAN
2021-09-27 A few struct renames and inverting PWM signals in FoC
2021-09-28 Add badly hacked LED control
2021-09-28 Allow LED's `on_while` to return a value
2021-09-28 Add LED Pulsing to calibrate_e_zero
2021-10-03 Major refactor of FDCAN part 1
    * Cleanup of the FDCAN messages into their respective files
    * Introduced a `Message` enum to avoid ID stomping
    [calibrate_e_zero.rs, driver.rs, fdcan.rs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]
2021-10-03 More steps towards cleaning up FDCAN
    * Peripheral and SRAM no longer public
    * Removed uninit stage.
    [driver.rs, fdcan.rs, main.rs]
2021-10-03 Simplify FDCAN more
    - Have callbacks own FdcanMessage
    - Don't block interrupts when handling received messages
2021-10-03 Note on new single-package BLDC
2021-10-04 First steps towards moving to PWM struct
2021-10-04 Extricated timer functionality into PWM
2021-10-04 Renamed TorqueControl and moved to FoC
2021-10-06 Still working on getting velocity control
2021-10-07 Dummy reply message for CalibrateEZero
2021-10-09 Swap magic number for actual peripheral in LED
    [led.rs]
2021-10-09 Added explicit on/off for LEDs
2021-10-09 Centralized sensor state
2021-10-10 Update SensorState to use SeqLock
2021-10-11 More fixes for host compilation. Still have an odd warning
    [driver.rs]
2021-10-11 Enable doctests for bldc again
2021-10-11 Unit tests and bugfix for iteratively_calculate_timer_config
    [timer.rs]
2021-10-11 Clear interrupt first before handling in case another one comes in
2021-10-12 Separate host tooling/tests since Cargo doesn't play nice with them
    [calibrate_e_zero.rs, cordic.rs, current_sensing.rs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]
2021-10-15 Fix angle_multiturn to be i32
    [ma702.rs]
2021-10-17 Fix radian PLL to be in line with the old MA702 version
    [encoder.rs]
2021-10-17 Clean up initial state of Encoder
2021-10-17 Centralized encoder state into encoder
2021-11-21 Notes on board
2021-11-21 Change encoder bandwidth to 200 rads/s
2021-11-23 Added IDs and enabled torque control
2021-11-24 Removed handling from fdcan, but borrow check issues.
    [controller.rs, driver.rs, fdcan.rs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]
2021-11-28 Migrating to pending upstream stm32g4 changes
2022-01-31 Add v2 KiCad project
    [v2.kicad_pcb, v2.kicad_sch]
2022-02-06 Added note about tello leg

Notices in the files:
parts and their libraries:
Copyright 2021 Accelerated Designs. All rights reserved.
